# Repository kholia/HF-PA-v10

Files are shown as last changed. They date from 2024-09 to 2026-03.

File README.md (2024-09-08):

Why?

We need a QRP PA which does NOT blow up (unlike those 3xBS170 and 4xBS170
designs). We believe that if the FETs blow up (despite best practices and
intentions but under less-than-ideal external conditions), then the design has
FAILED!

[Inspirational Video Link](https://www.youtube.com/watch?v=4r7wHMg5Yjg)

Update (August-2024): https://github.com/kholia/HF-PA-v10/tree/master/IRFP-Hacks-v5-SMD
(or v4 for THT regulator) and SUPSiC GC2M0280120D is all you need for 30W
All-HF PA for 4 USD. For 30W All-HF PA @ 8.5 USD, my tested MOSFET is CREE
C2M0280120D. Use 7815 regulator for powering the UCC gate driver when using the
`*C2M0280120D` MOSFET. SUPSiC GC3M0280090D works very well too and is our top
choice now (as of September, 2024).

Important update (February-2024): LC match for IRF510 @ 28 MHz. 7 turns FT50-6
and 220pF capacitor. Corrected PAE figure is around 50%. 30v @ drain produces
roughly 10W of clean'ish looking RF output. 24v @ drain produces 6W @ 28 MHz.
17v @ drain produces 3.7W.

March-2024 update: LC match for IRF510 @ 50 MHz. T50-6 4 turns and 180pF
capacitor. 24v @ drain produces clean'ish 28.8 Vpp (~2W). PAE is around 25%.
Such is life...

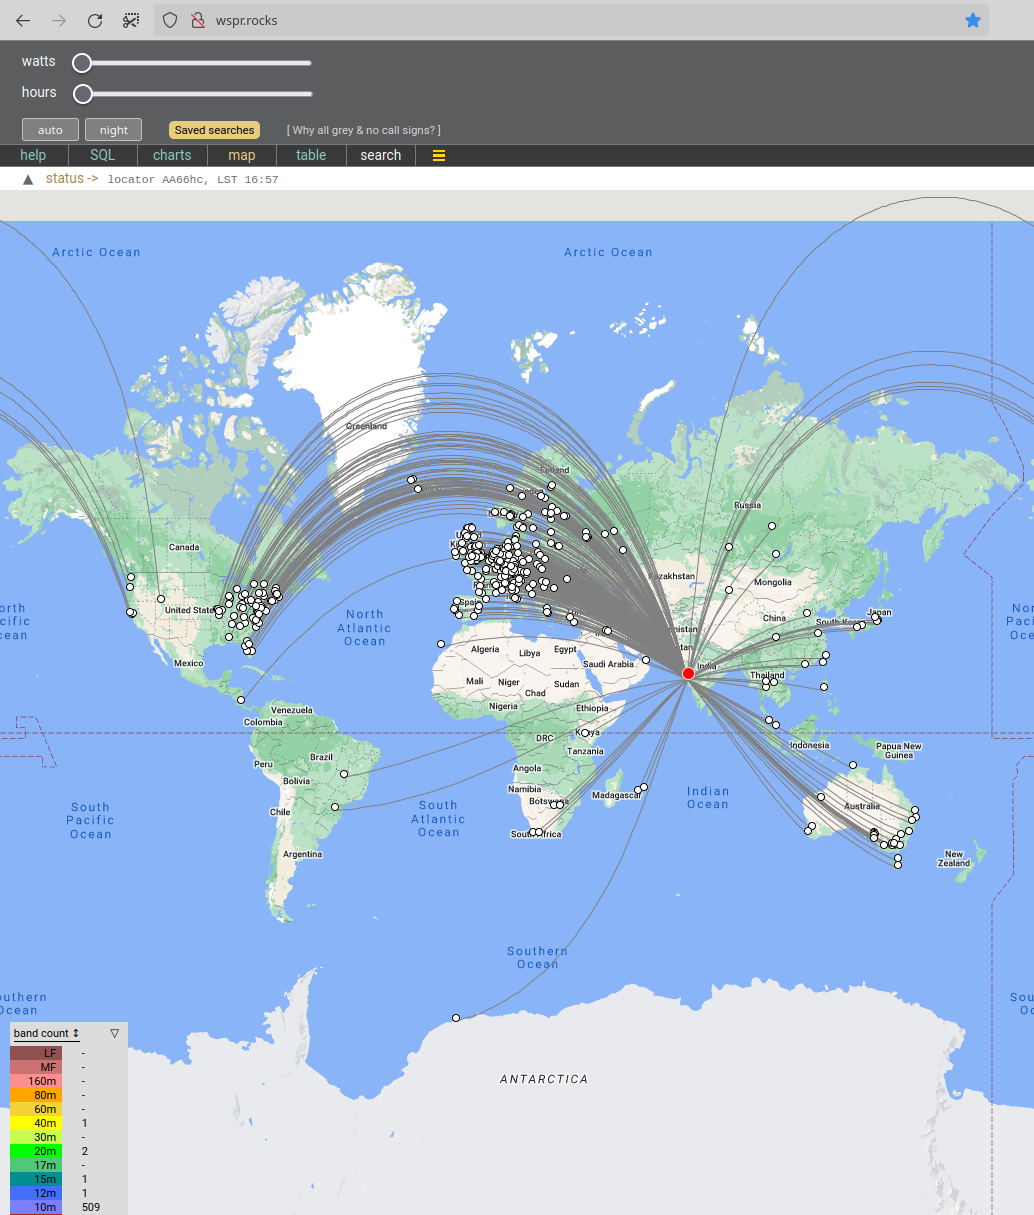
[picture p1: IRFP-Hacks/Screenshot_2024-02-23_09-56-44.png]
WSPR results


Update (29-September-2023): By removing the gate resistor, we firmly push the
amplifier into more Class-D operation. The MOSFET now remains as cool as a
cucumber!

Update (10-September-2023): The PCB was successfully validated!

Output is 7 to 8 W (before LPF) over a range of 160m to 10m as expected, with a
15V SMPS power supply. With a Pro-BPF attached, the power output is ~5W even at
28 MHz with IRF510! It even puts out 2W @ 50 MHz!

Amplifier characterization (@ 30.7 MHz for some reason, before LPF):

7 volts -> 2W

8 volts -> 3W

9 volts -> 3.5W

10 volts -> 4W

11 volts -> 5W

12 volts -> 6W

14 volts -> 8W

Efficiency is in the range of 45 to 50% which isn't bad ;)

Another result: 17 volts. 14 MHz. NKK LPF. 17.3W DC in. 57.6 clean Vpp on
scope. 8.3W clean RF output @ 48% efficiency!

BOM cost (minimal version): < 450 INR only - beat this! ;)

Note: HF-PA-v10 is also known as `CoolAMP (TM)`.

Build Notes:

- Use a 15V / 16v power supply.

- If you want to use a 13.8V power supply, then

  - Do NOT install the 78M12 regulator

  - Bridge the JP2 jumper

- Use adequate heatsinking. I use a 100x100x200 aluminium block with a 12v fan
  for doing WSPR activities. The MOSFET temperature stays under 45 degrees this
  way.

- PTT is active high - 3.3v is enough to trigger PTT.

- To skip the PTT sub-circuit, bridge the AOD407 MOSFET's source to drain.

- This amplifier can be directly driven by Si5351 (use 8mA drive setting)!

- IMPORTANT: For safety and RF output control, use a `10A DC-DC Step-down
  Adjustable Constant Voltage Module` or something similar.

  - https://robu.in/product/10a-dc-dc-step-down-adjustable-constant-voltage-module/

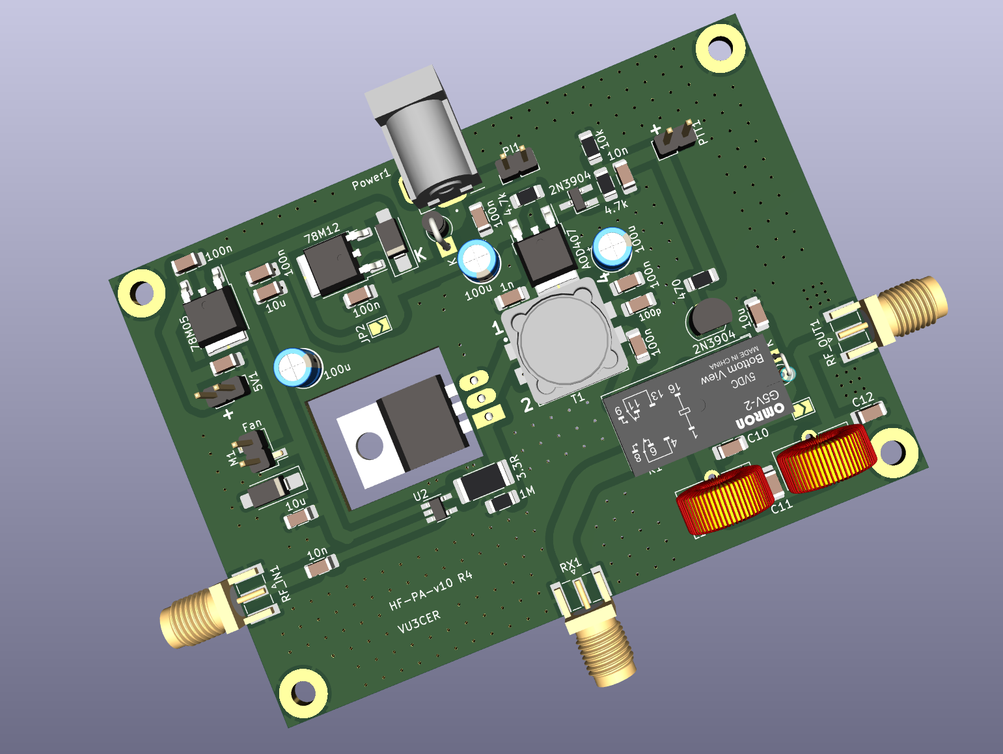
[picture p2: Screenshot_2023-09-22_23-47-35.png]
PA 1


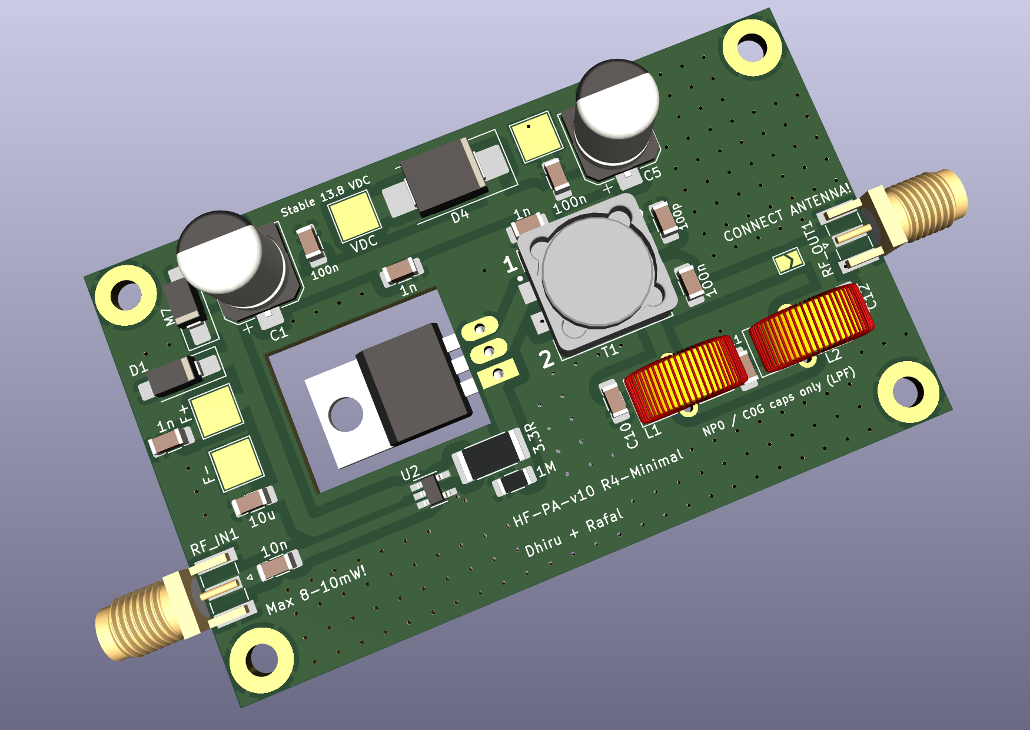
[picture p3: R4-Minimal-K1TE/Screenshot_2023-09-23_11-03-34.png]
PA Minimal


Results:

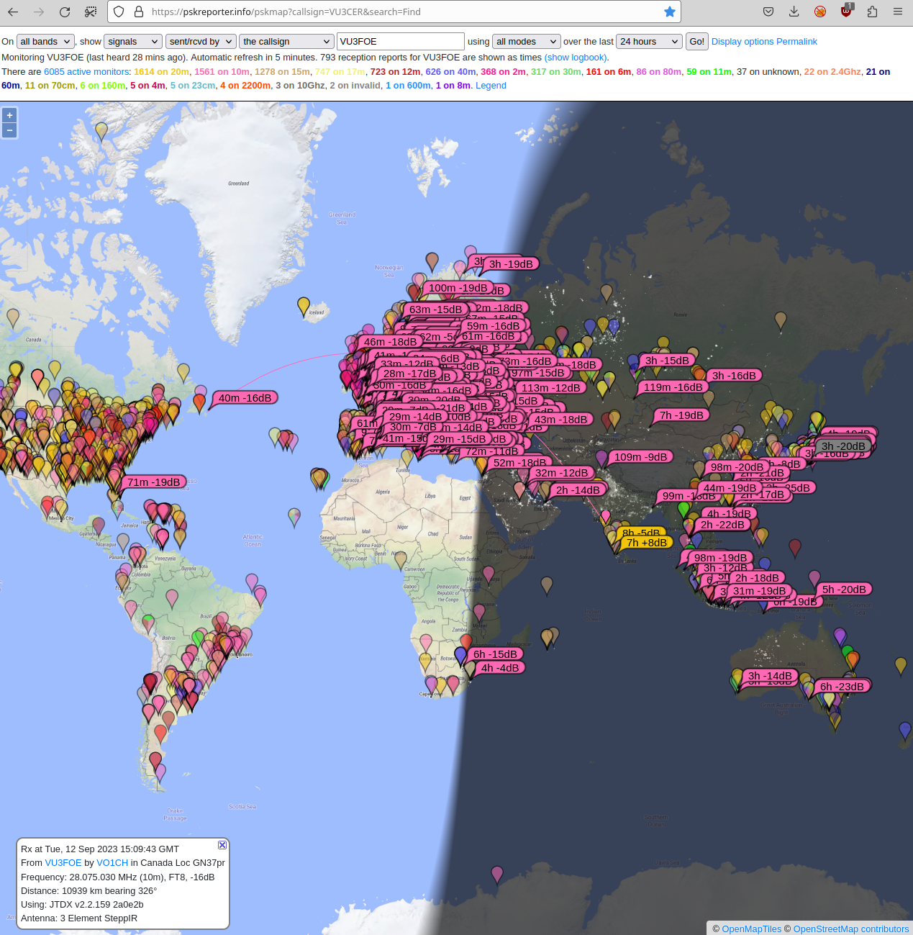
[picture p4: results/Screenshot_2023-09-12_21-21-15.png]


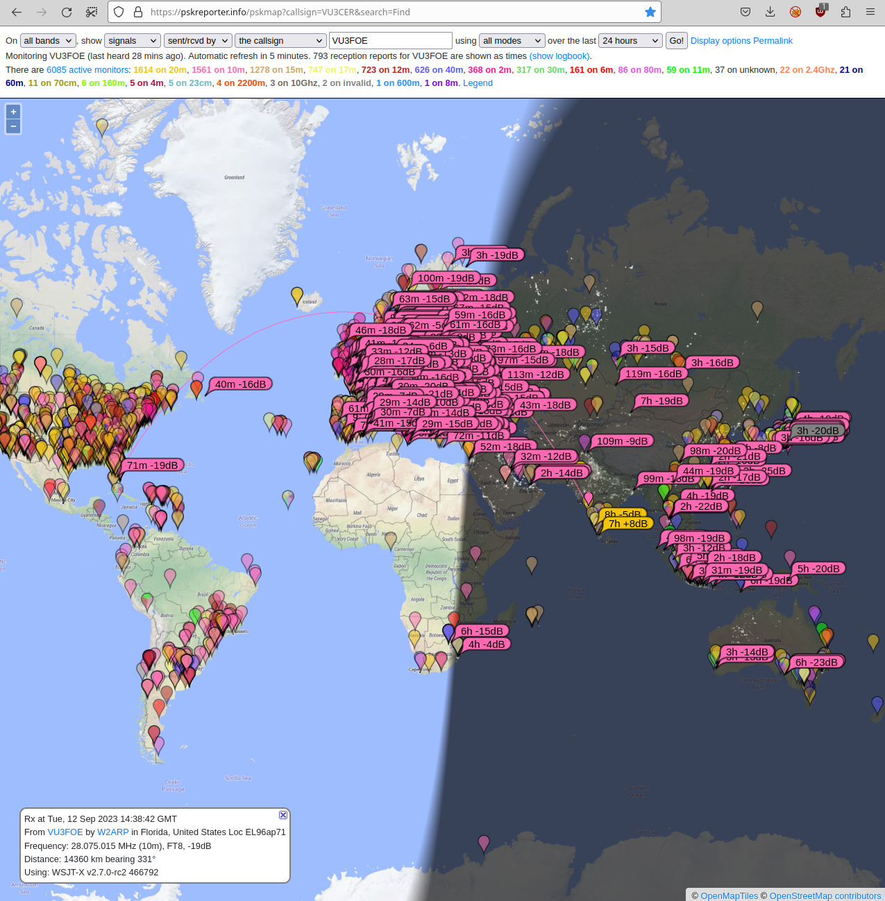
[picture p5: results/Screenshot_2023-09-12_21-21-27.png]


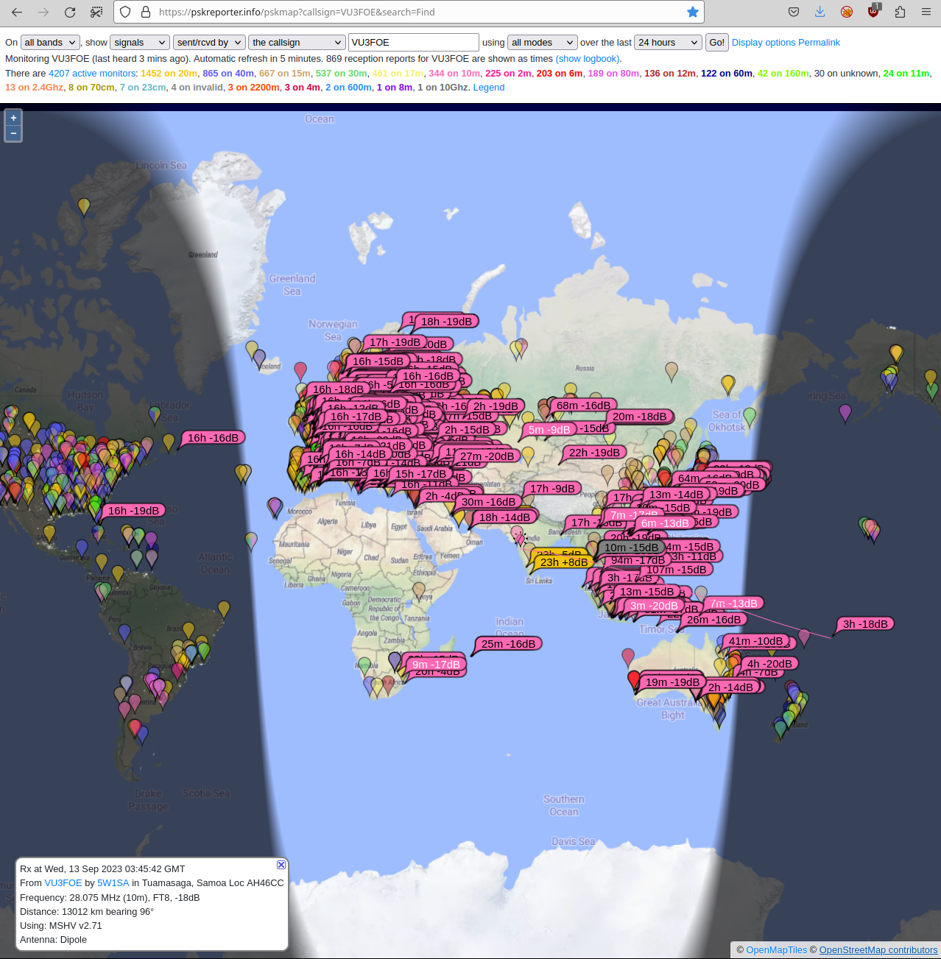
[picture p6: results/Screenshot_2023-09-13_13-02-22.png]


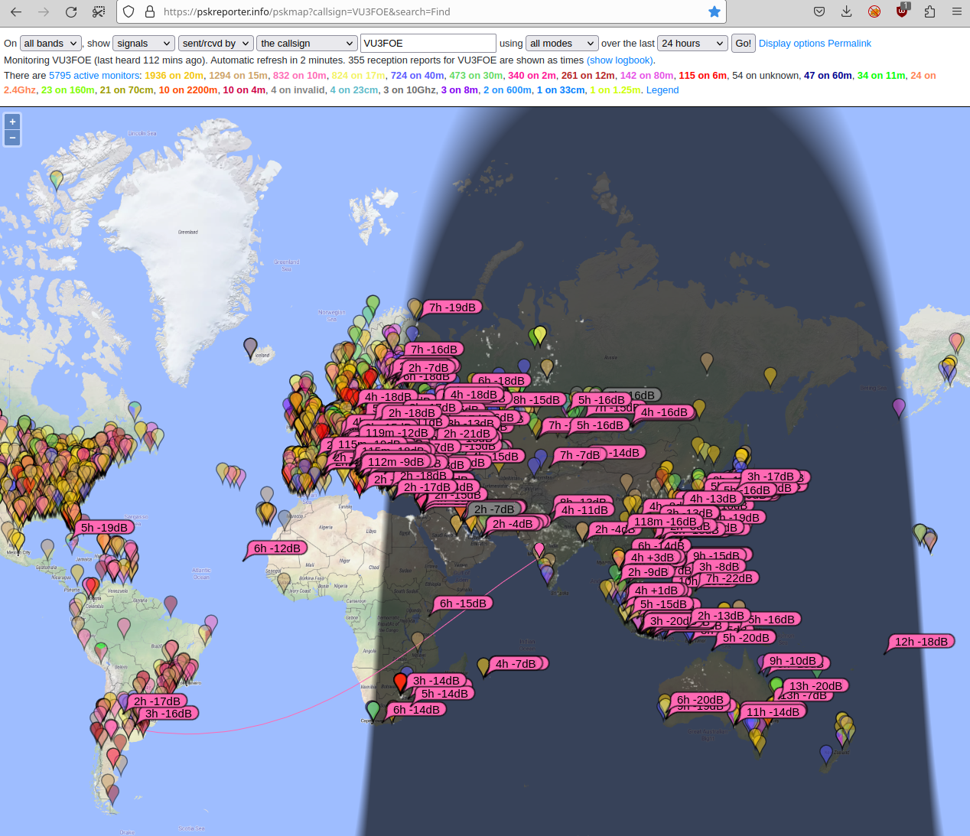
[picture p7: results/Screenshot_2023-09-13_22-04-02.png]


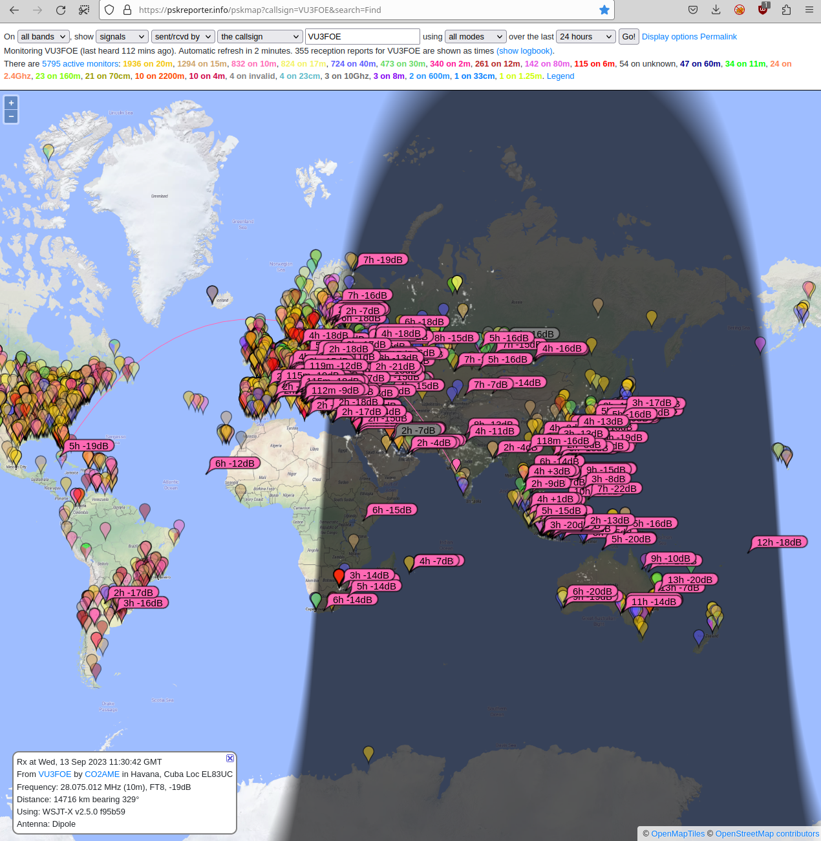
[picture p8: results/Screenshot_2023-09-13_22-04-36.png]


Fun on WSPR:

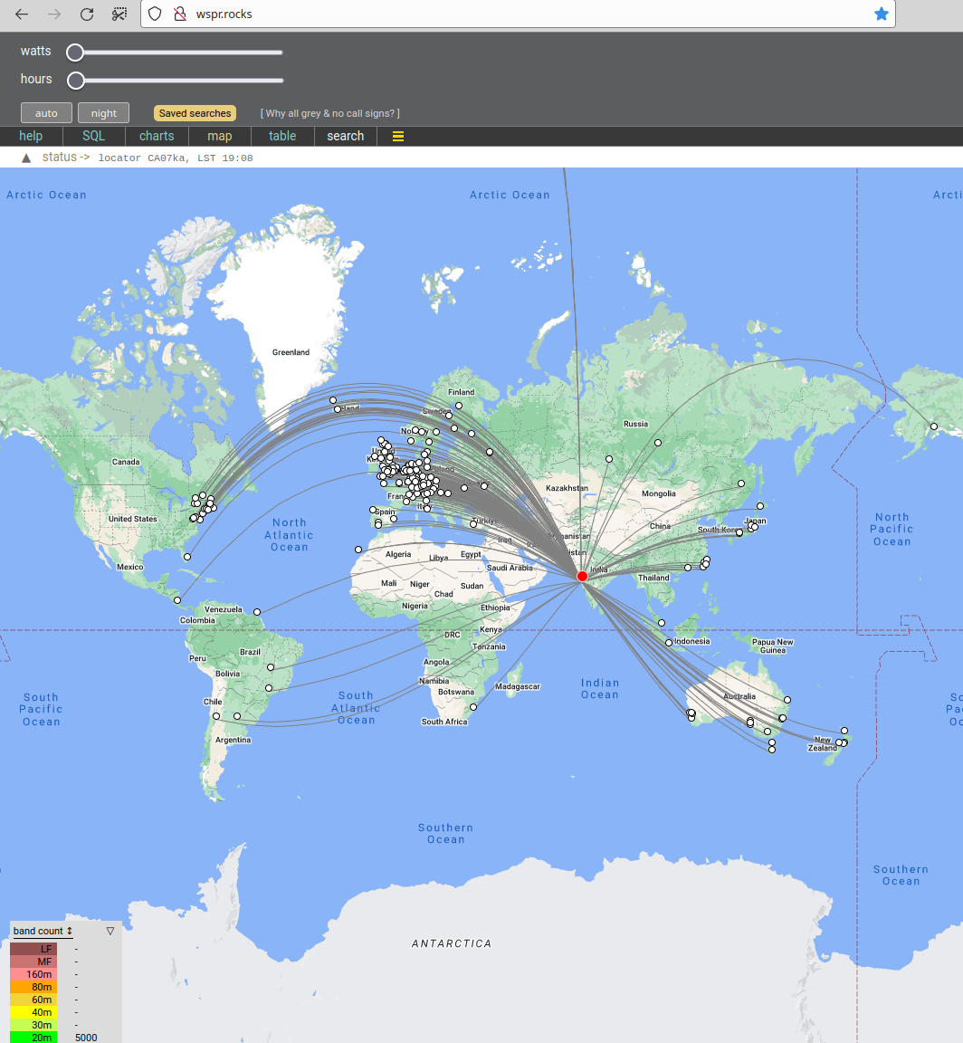
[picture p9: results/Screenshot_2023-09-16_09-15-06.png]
WSPR 1


Note: I am using a 5-meter long EFHW antenna tuned for the 10m band along with
~45 meters of HLF-240 coax. Your results should be better than mine ;)

Quick Hacks:

I am using one v10 board (on low power setting of ~1 to 2W) to drive the second
v10 board.

The second v10 board has IRF530 on it. It uses a simple 3R3 SMD drain choke,
240nH inductor (8 turns on T50-6) + 470 pF LC match for the 20m band at the
output side.

The power output is 20W+ with 30v at the IRF530 drain. While this is fine for
FT8, we decrease the output power to 9 to 12W for WSPR mode (considering
derating, heat dissipation, fear of "flash over")

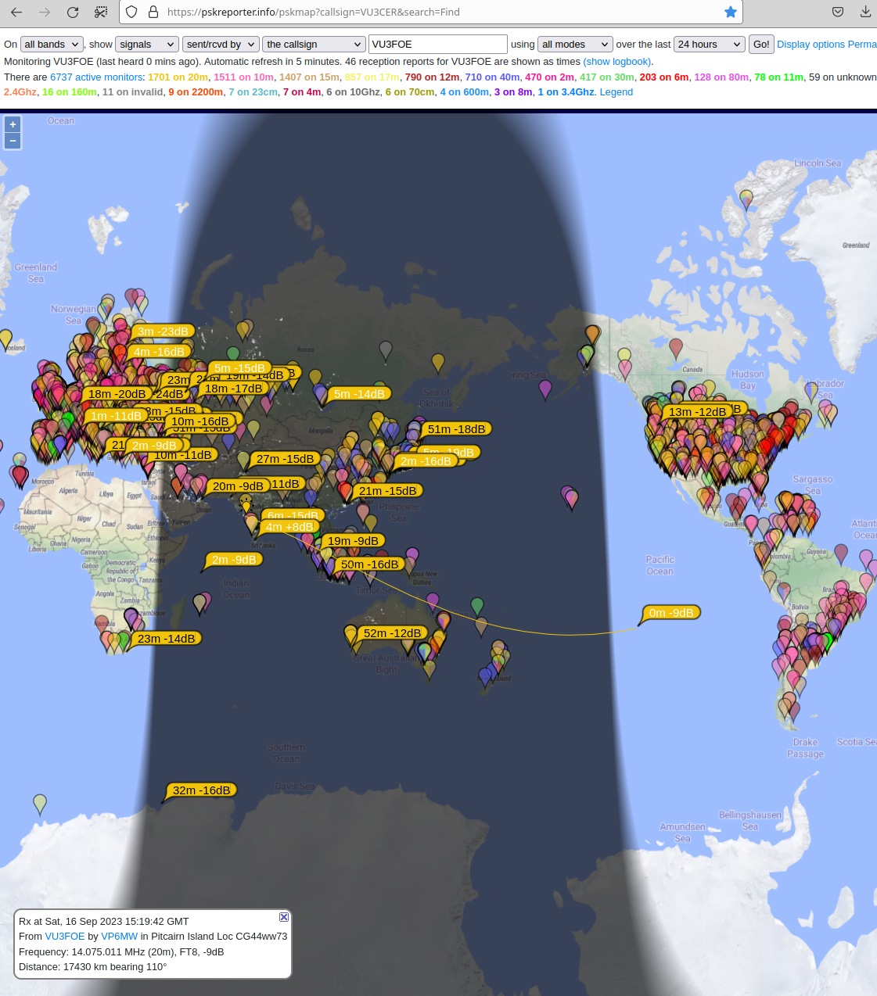
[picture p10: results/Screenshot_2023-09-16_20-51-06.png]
Results for IRF530 hack


December-2023 update: We can now use IRFP140N (with its massive TO-247 package)
to generate around "20W" safely for WSPR. We drive the IRFP140N MOSFET directly
with the UCC driver chip now.

Settings: UCC driver at roughly 12v. With LC match set for 20m band (NB!).

IRFP140N @ 28v drain @ 14 MHz -> 22W

IRFP140N @ 28v drain @ 3.5 MHz -> 20W (for Rafal)

IRFP140N @ 28v drain @ 7 MHz -> 20W

We believe we can push 25W easily by feeding 14v to 15v to the UCC driver chip.

The "final" IRFP140N MOSFET remains as cool as a cucumber, pretty boring -
right? Where have the "exciting" days of the MOSFETs blowing up in your face
gone? Just kidding!

NB: To overcome antenna losses (~2.0 SWR 20m dipole), lossy 50m meters of
HLF-200 coax, we need to generate around 15W+ on the amplifier side.

```
In [1]: 15W * 0.88 (SWR losses) * 0.40 (coax losses)
Out[1]: 5.28
```

PA protection:

- We plan to use INA219 to monitor current consumption, and to terminate TX if
  anomalies are detected.

- Use `thermocouple` attached to the MOSFET's body using thermoglue to monitor
  the temperature, and to terminate TX if anomalies are detected.

New discoveries (via https://github.com/rafal-rozestwinski):

- Power output is 1 to 1.5W on 50 MHz.

- The PA survives open and short conditions but protections are recommended in
  any case.

  - INA219 based current monitoring

  - Thermocouple based temperature monitoring

- We do NOT recommend the old-skool SWR monitoring approach due to its
  complexity (for end-users).

Learnings:

- Keep the IRF510's gate voltage <=9 volts.

  If the IRF510's gate voltage is too high (i.e. when IRF510 is over-driven),
  it results in super wide-band distorted noisy signal on the output - you
  don't want that ;)

  If you want to feed high voltages to IRF's drain, then use a regulator (9v)
  for powering the UCC driver chip.

Joining In:

Are you interested in such projects, and spam-free technical discussions?

If yes, you might be interested in joining [the 'HAMBREWERS' Telegram group](https://t.me/+TwzGyKGe8_QI_B3y).

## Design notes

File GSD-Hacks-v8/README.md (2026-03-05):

This version uses a GaN gate driver (MX1025D) and GSD pinout TO-252 package GaN FET. It also uses a cost-effective Chinese `coupled inductor`.

Works without extra cooling at 12V to 15V drain. 20V drain needs extra cooling for heavy duty cycles. 

For WSPR, I recommend running at 7.5V drain with ~1W output.

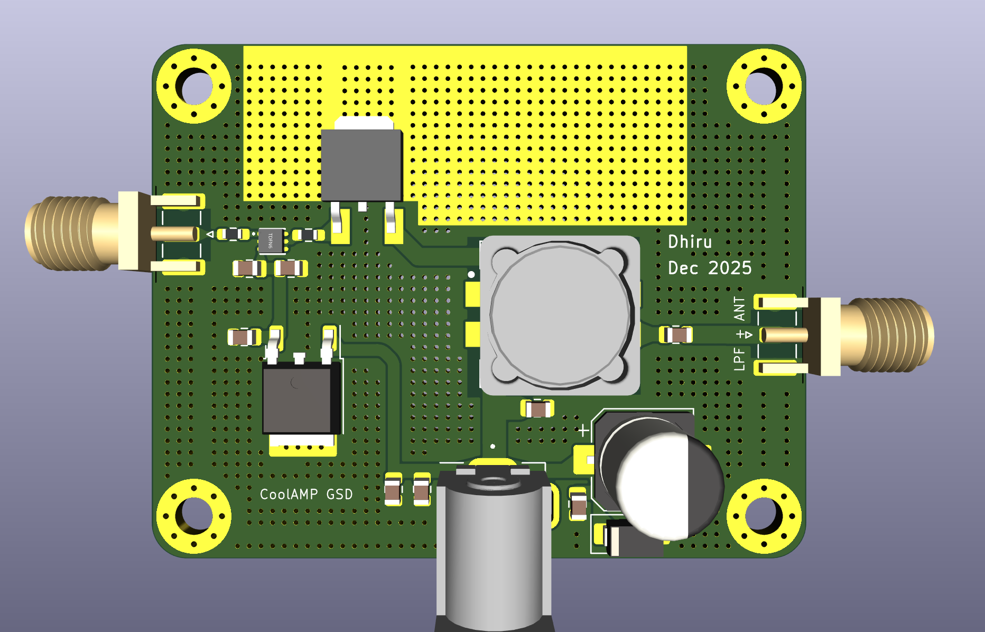
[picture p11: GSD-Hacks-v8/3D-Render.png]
3D PCB Render


This is the same as `GSD-Hacks-v7` but with an 10 ohms series resistor added to the TTL input port.

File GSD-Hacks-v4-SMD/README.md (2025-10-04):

This version uses SOIC-8 gate driver (NCP81074ADR2G) and GSD pinout TO-252 package FET.

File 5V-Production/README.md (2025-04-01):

This version was created to allow easier experimentation with `VCC = 5v`.

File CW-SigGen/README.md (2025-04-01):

Many RF MOSFETs specify a CW input signal in their datasheets.

This `CW-SigGen` software produces a suitable CW input signal for testing power
amplifier circuits.

This was tested on a WeMos D1 Mini board connected to a Si5351 module.

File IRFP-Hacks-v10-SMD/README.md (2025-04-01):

This version was created to allow easier experimentation with `VCC = 5v`.

This version also uses SOP-8 gate driver(s).

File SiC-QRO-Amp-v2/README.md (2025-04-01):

NB: This design is inspired by the wonderful `Single NXP MRF-101 Eval Board`
project by Jim Veatch.

This project is similar to `SiC-QRO-Amp` one.

Changes:

- Use a SOIC-8 MOSFET driver instead of our usual SOT23-5 one

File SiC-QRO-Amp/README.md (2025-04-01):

NB: This design is inspired by the wonderful `Single NXP MRF-101 Eval Board`
project by Jim Veatch.

https://sites.google.com/site/rfpowertools/rf-power-tools

Backstory: Sometimes we all need a bit of "QRO" in life...

So we give you the `Baby QRO` switching amplifier!

MRF101 is too "precious" for WSPR usage, especially with its self-limiting
TO-220 package.

This PCB was tested in late January-2025 and it works great. Produces 100W+ at
50V drain on 7 MHz. The gain drops with increasing frequency but not too badly!

Results:

[Conservative] 9V driver, 43V drain -> ~70W @ 7 MHz, 60W @ 14 MHz, 30W @ 28 MHz

12V driver, 43V drain -> 50W @ 28 MHz, ~70W @ 7 MHz. Efficiency is close to 50
percent on 28 MHz it seems. 55% efficiency at 7 MHz.

[TOP] 12V driver, 48V drain -> 60W @ 28 MHz, 100W @ 7 MHz.

Cost for 100W: Around 15 dollars (for all including PCB and BOM components)

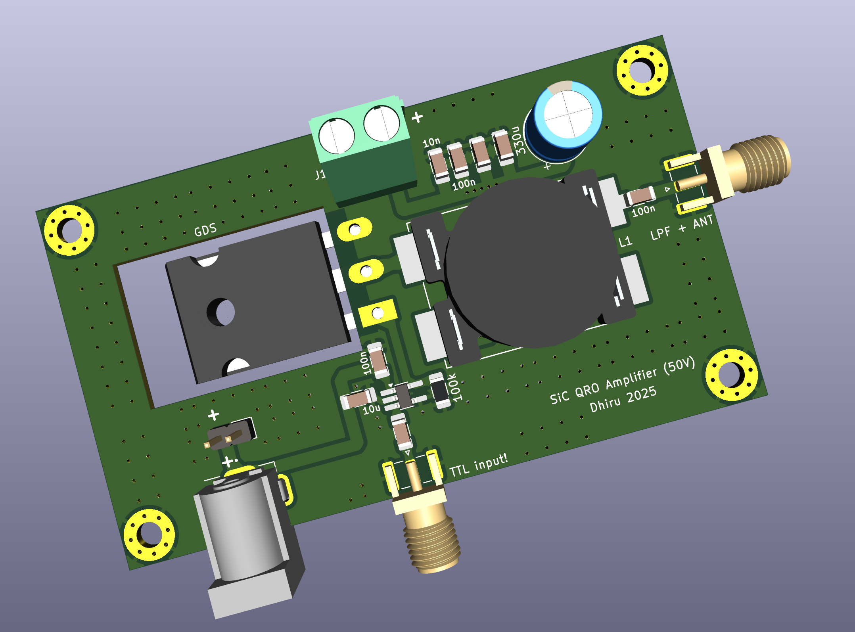
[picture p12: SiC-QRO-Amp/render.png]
Render


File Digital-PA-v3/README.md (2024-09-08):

# Digital-PA
A digital mode power amplifier for 160-10m.
Created using Kicad 7.0.6.

Licensed under Attribution-NonCommercial 4.0 (CC BY-NC 4.0).

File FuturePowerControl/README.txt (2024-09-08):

https://electronics.stackexchange.com/questions/630076/buck-converter-adjustable-output-voltage-using-digital-potentiometer

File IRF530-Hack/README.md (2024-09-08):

IRF530 hack. ~1.5W in, 20W+ out on 20m @ 25v to 30v drain.

ATTENTION: Use a fast fan when doing digital modes using this PA.

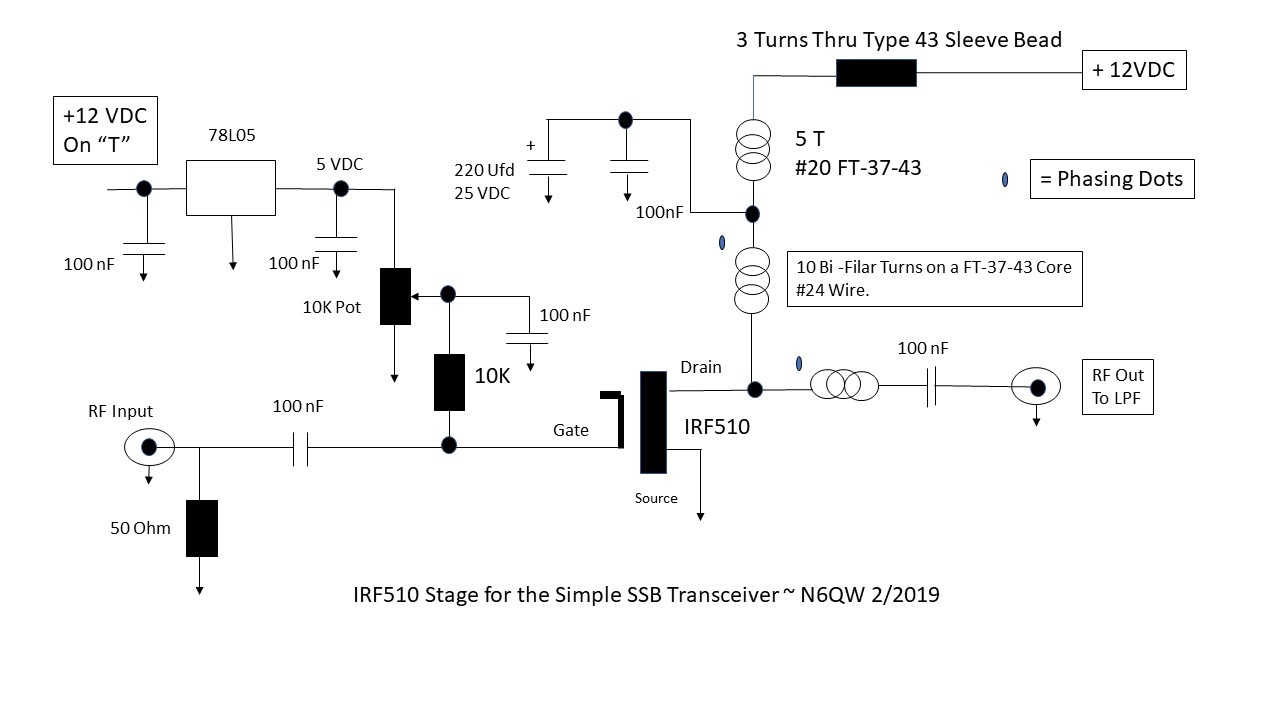
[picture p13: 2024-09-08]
Linear-Amp-SSB-v1/IRF510 Schematic.jpg

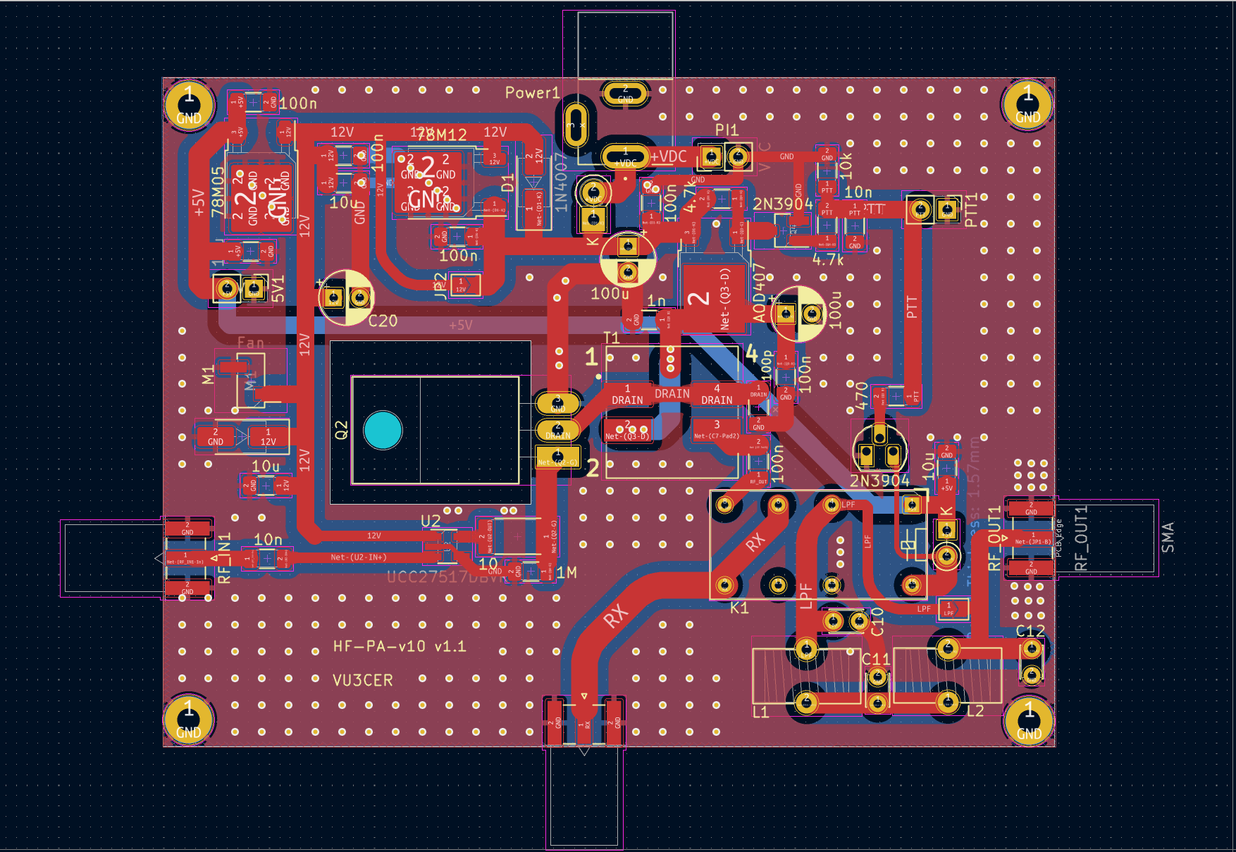
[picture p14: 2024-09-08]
Screenshot_2023-08-26_22-36-42.png

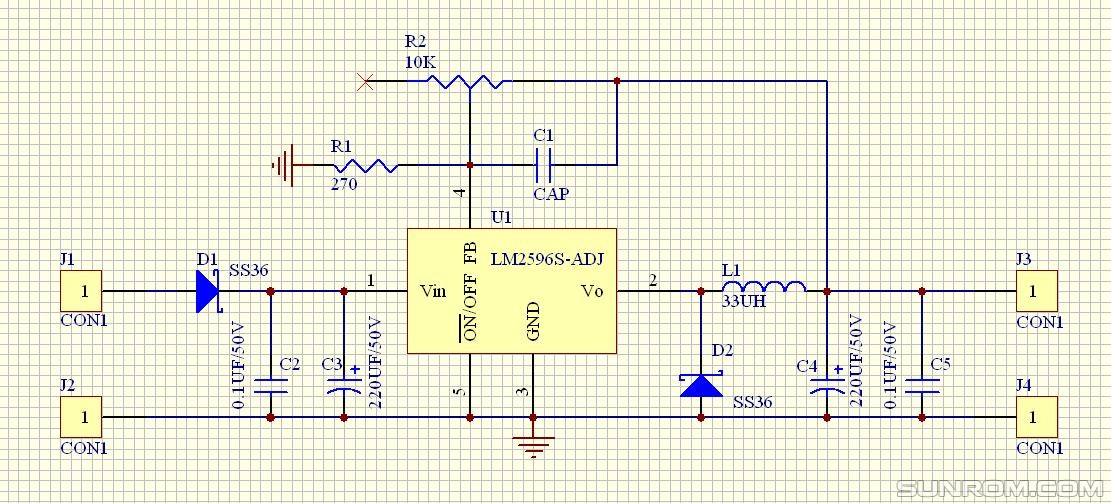
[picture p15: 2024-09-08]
FuturePowerControl/sch.jpg

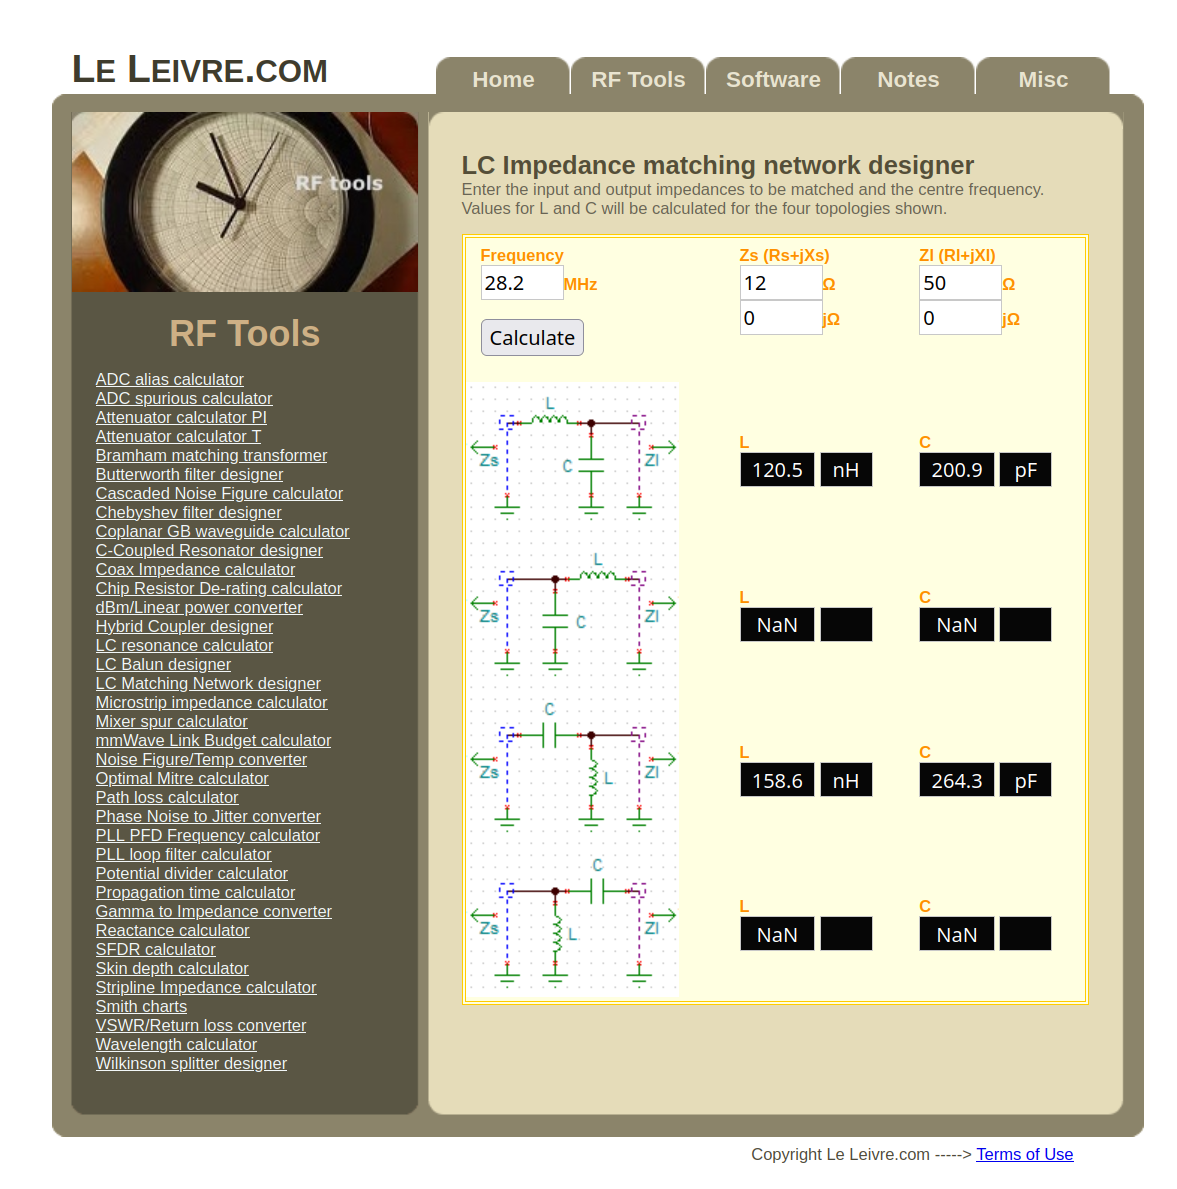
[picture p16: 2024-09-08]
IRFP-Hacks-v7-SMD-With-SSB/info/Screenshot_2024-04-25_09-21-08.png

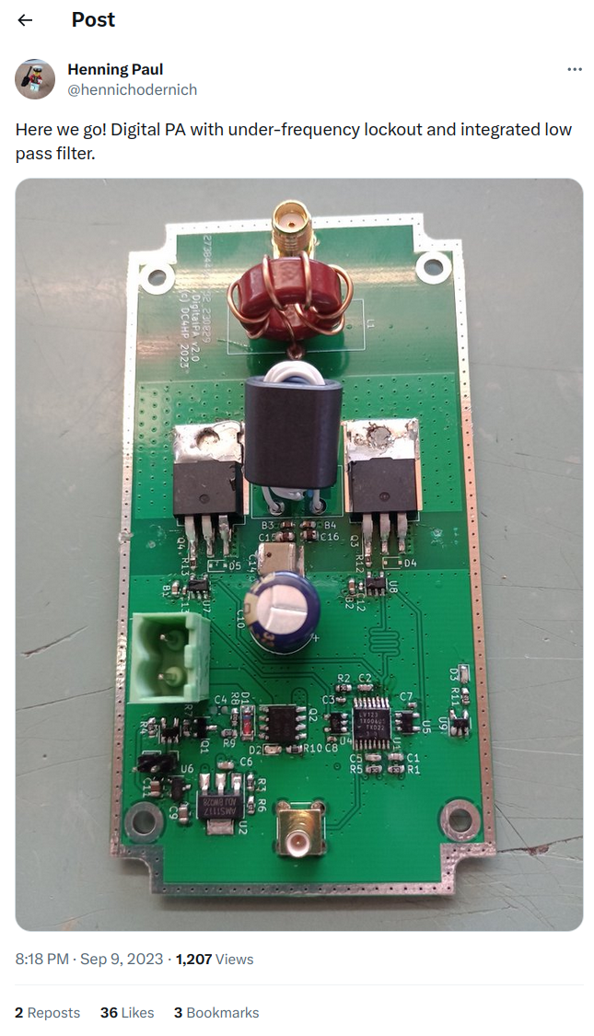
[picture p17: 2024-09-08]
info/Screenshot_2023-09-10_00-21-56.png

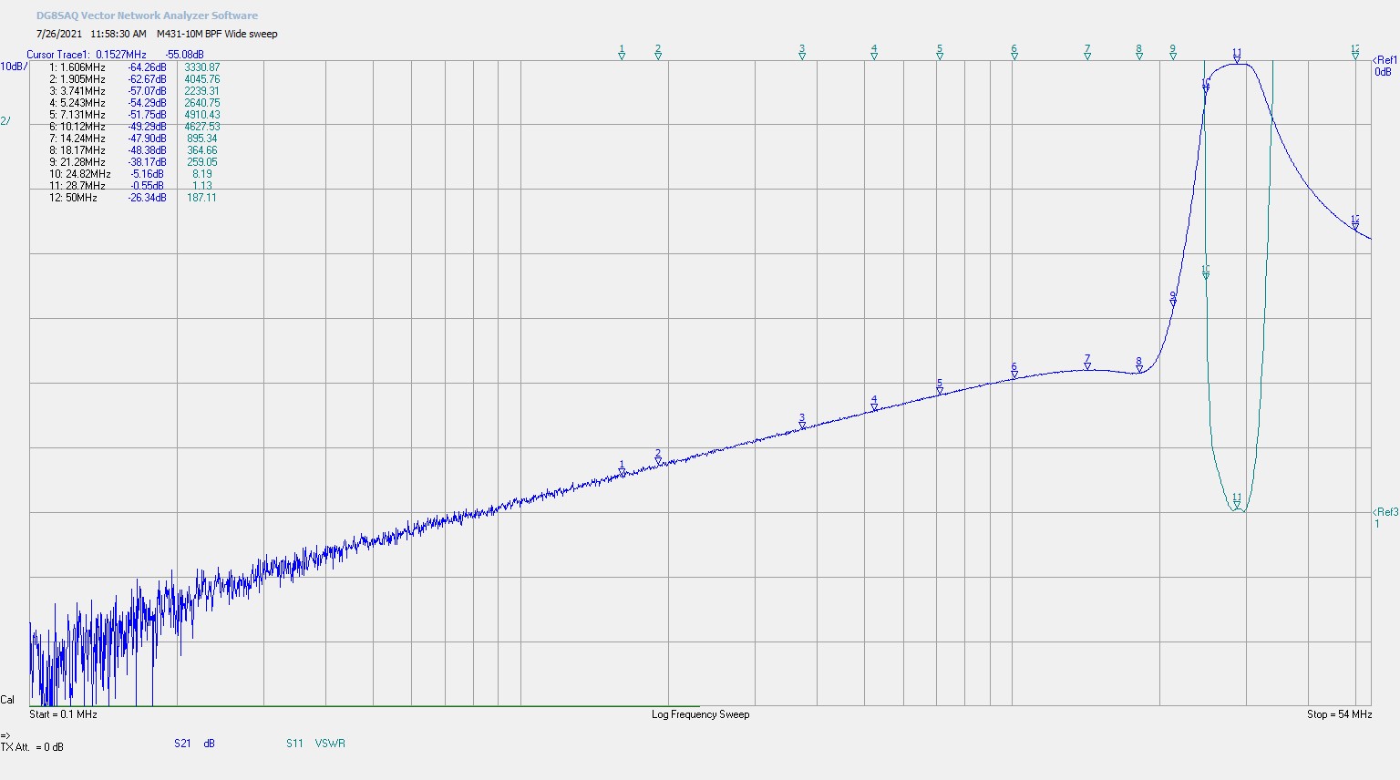
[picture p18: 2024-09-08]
info/M431_10M_Wide.jpg

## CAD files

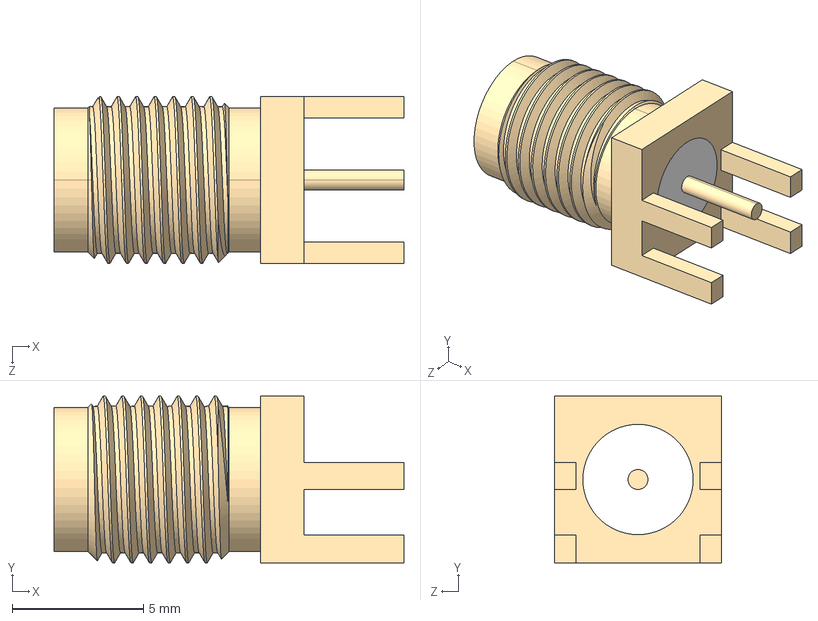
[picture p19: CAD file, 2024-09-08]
3-Pole-LPF/models/CON-SMA-EDGE-S--3DModel-STEP-56544.STEP
13.3 x 6.35 x 6.35 mm

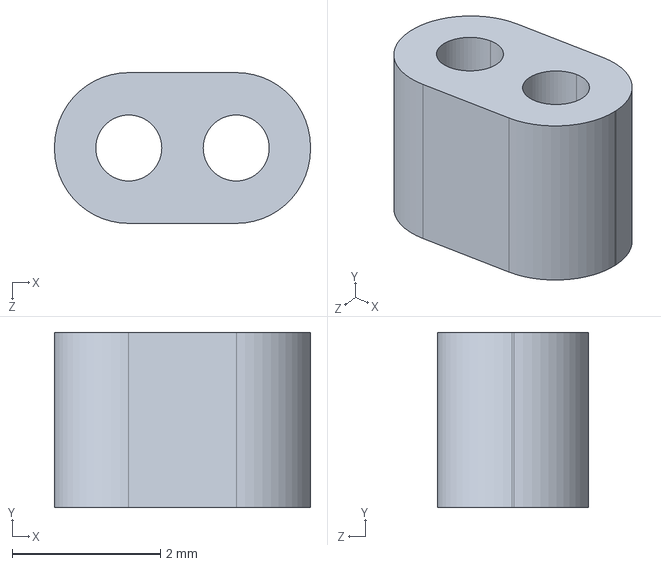
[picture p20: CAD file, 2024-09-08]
Digital-PA-v5-Prod/models/User Library-BN43-2302.STEP
3.45 x 2.36 x 2.03 mm

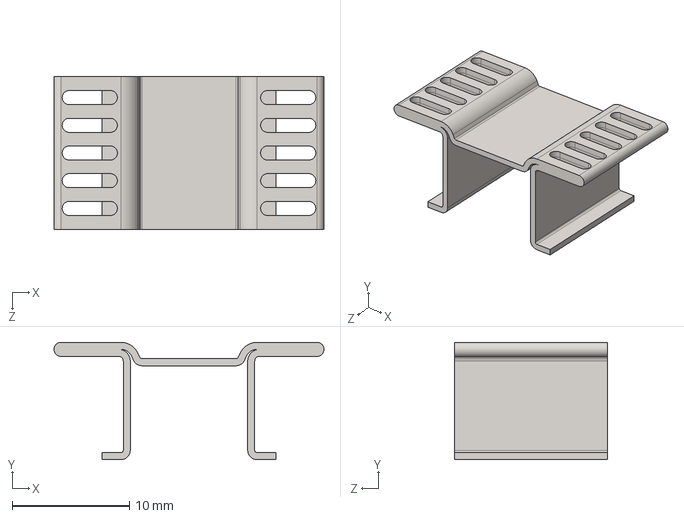
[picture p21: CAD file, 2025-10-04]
GSD-Hacks-v8/models/FK_244_13_D_PAK_TR.stp
23.0 x 10.0 x 13.0 mm

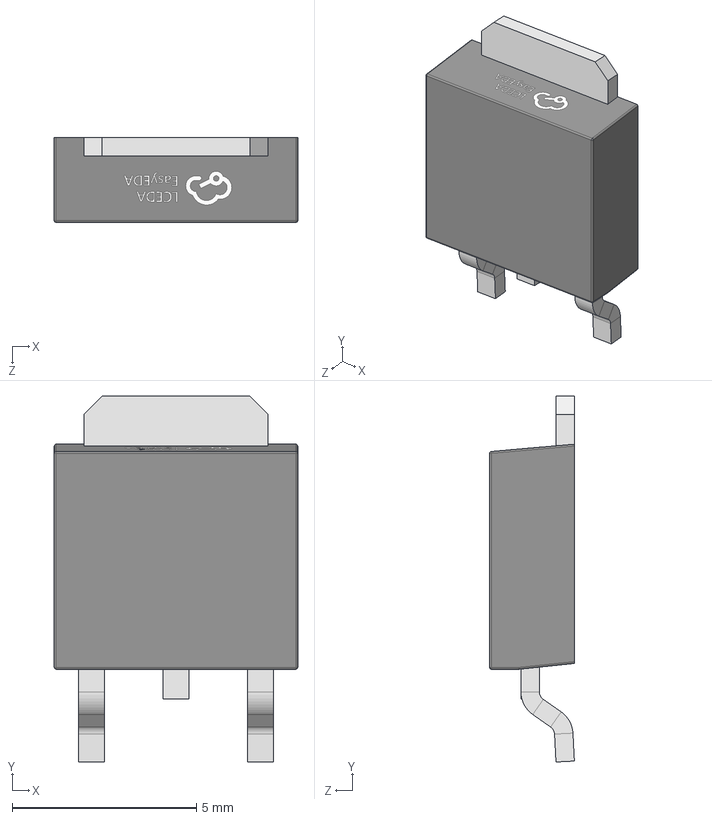
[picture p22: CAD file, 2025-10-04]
GSD-Hacks-v8/models/TO-252-2L-3P_L6.6-W6.1-H2.3-LS10.1-P4.6.step
6.60 x 9.92 x 2.30 mm

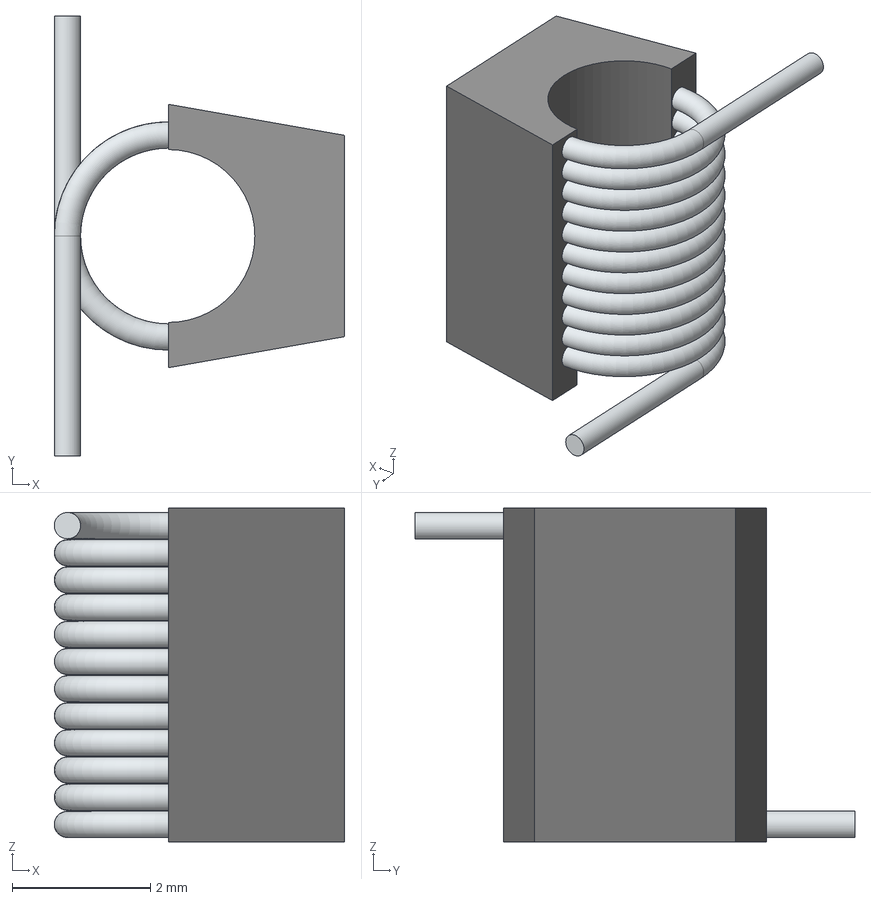
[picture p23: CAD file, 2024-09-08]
MRF101-Hack/models/WE-CAIR_4248 (rev1).stp
4.20 x 6.36 x 4.83 mm

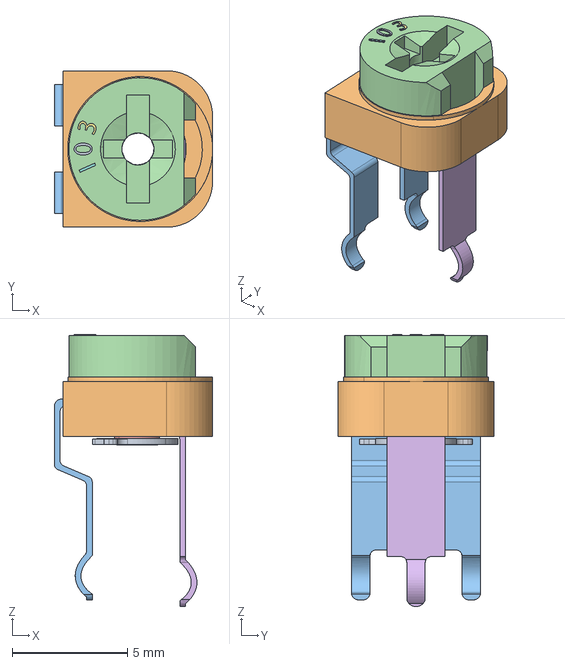
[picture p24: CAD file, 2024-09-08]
UCC-Driver-Board/models/Poti_10kohm.stp
6.88 x 6.80 x 11.8 mm

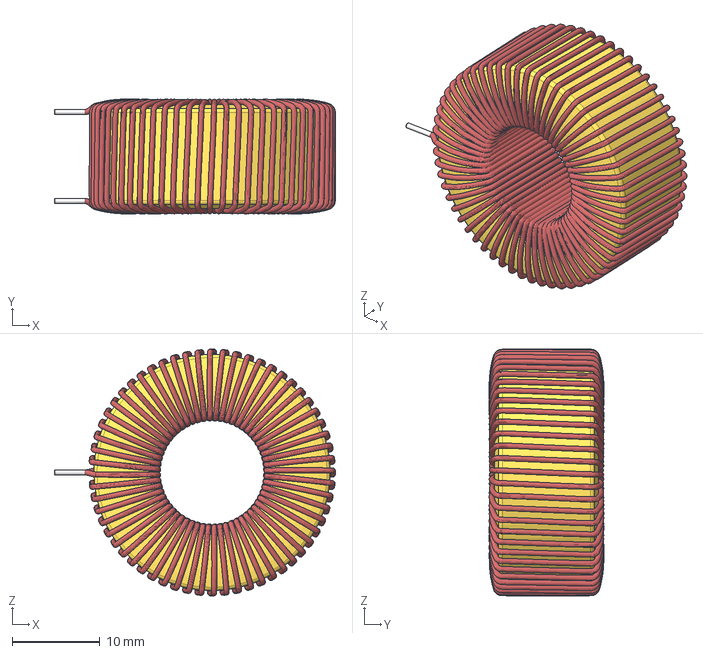
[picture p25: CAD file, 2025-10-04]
GSD-Hacks-v8/models/Toroidal_Inductor_330uH_3A.stp
32.1 x 13.1 x 28.2 mm

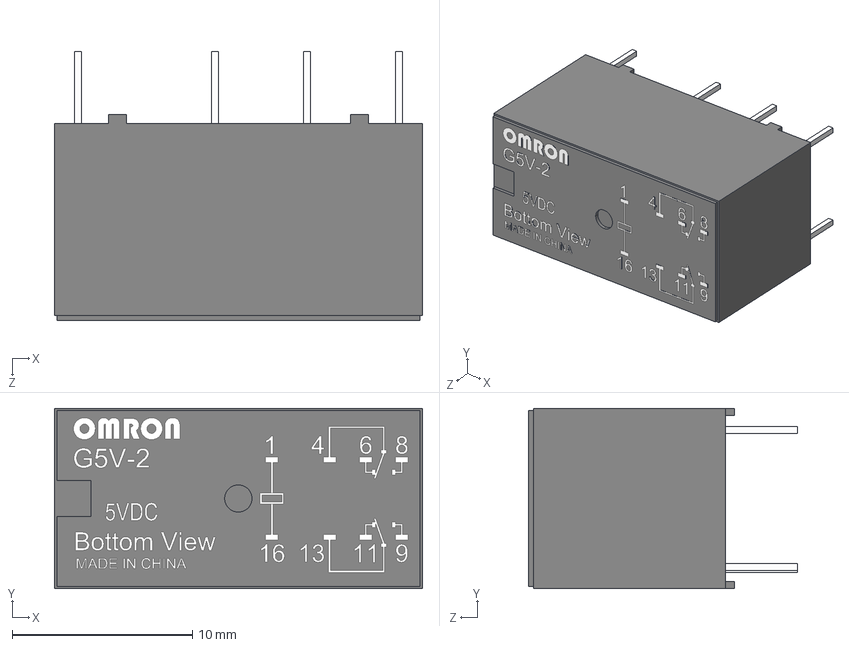
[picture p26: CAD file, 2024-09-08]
MRF101-Hack/models/User Library-OMRON G5V-2.STEP
20.4 x 10.0 x 14.9 mm

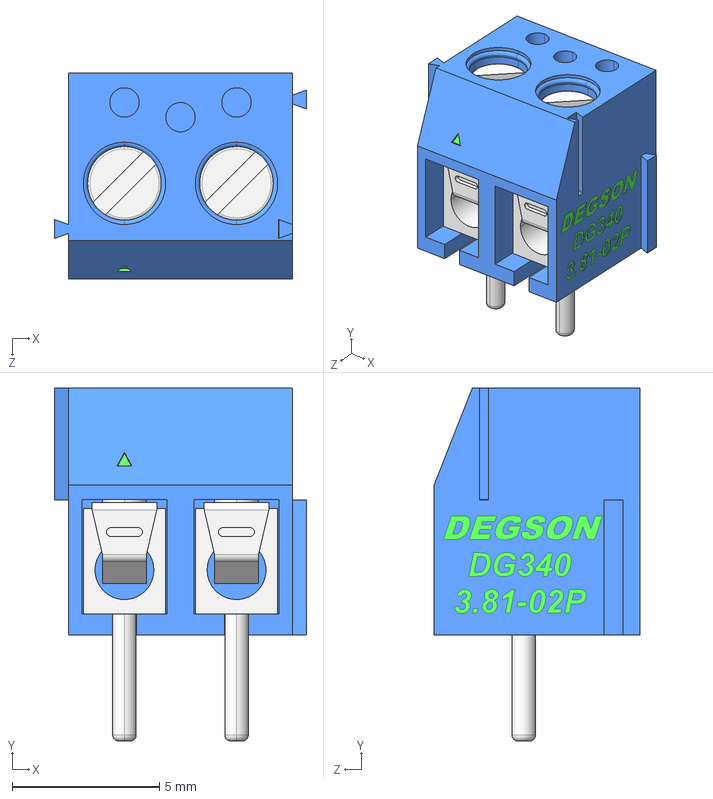
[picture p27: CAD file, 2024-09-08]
MRF101-Hack/models/DG340-3.81-02P-12-00AH.STEP
8.58 x 12.0 x 7.00 mm

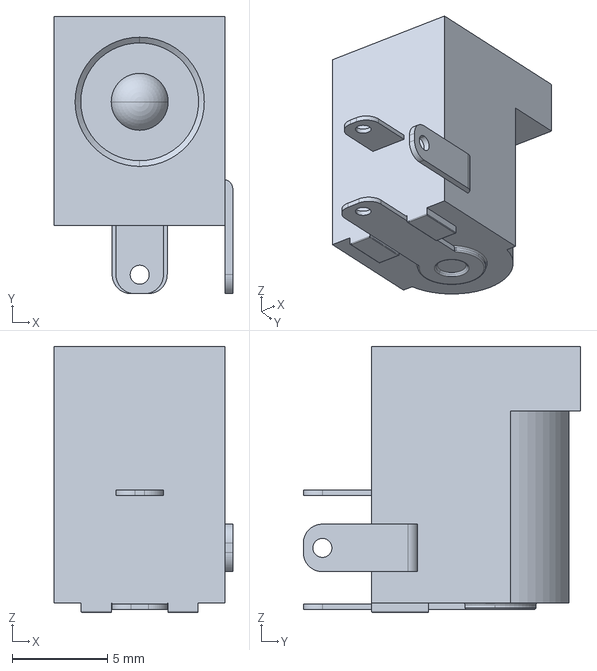
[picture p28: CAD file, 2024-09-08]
GSD-Hacks-v8/models/DC-005-5A-2.0.step
9.40 x 14.6 x 14.0 mm

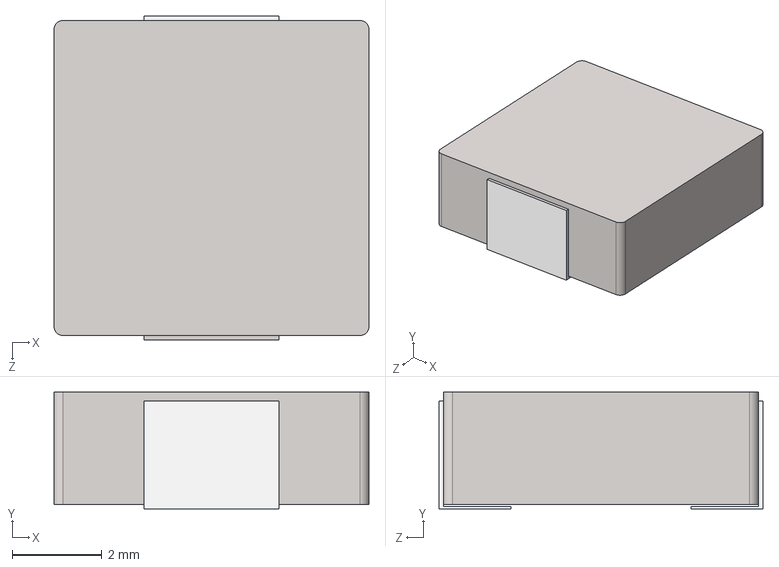
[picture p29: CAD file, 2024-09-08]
MRF101-Hack/models/Inductor_7x7x2.5.STEP
7.00 x 2.60 x 7.20 mm

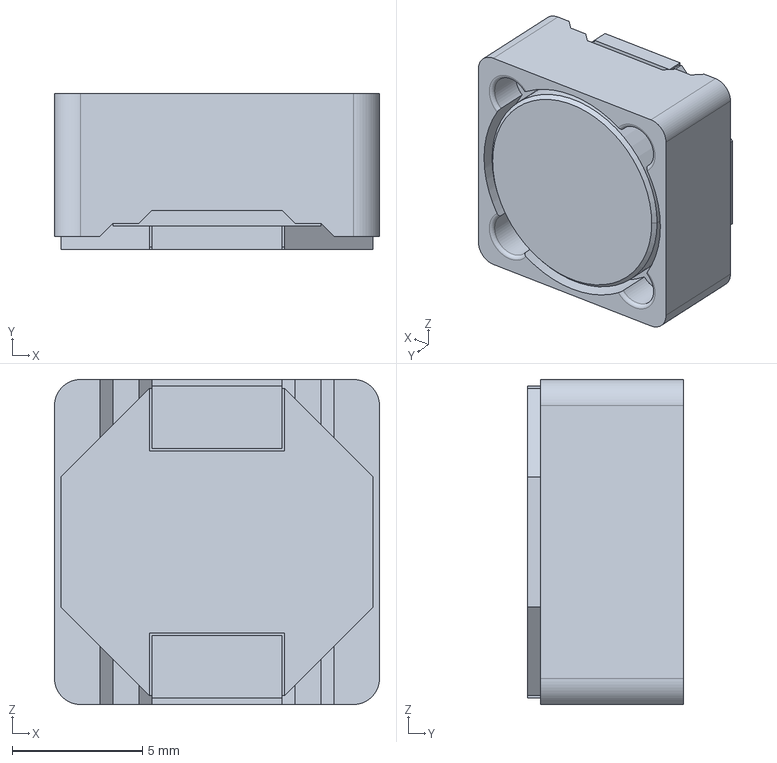
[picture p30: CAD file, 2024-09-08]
MRF101-Hack/models/SRR1260-4R7Y.stp
12.5 x 6.00 x 12.5 mm

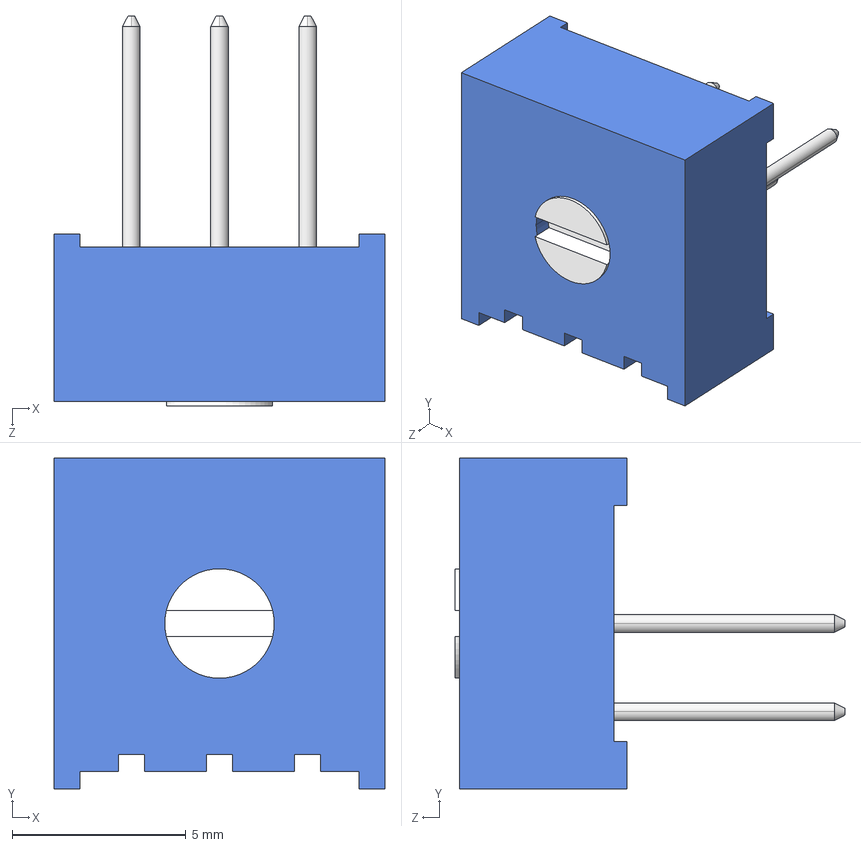
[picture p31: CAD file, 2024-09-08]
MRF101-Hack/models/User Library-3386P.STEP
9.53 x 9.53 x 11.2 mm

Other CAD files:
5V-Production/models/UCC27517DBVR.step
Digital-PA-v3/models/144743.stp
Digital-PA-v3/models/UCC27517DBVR.step
Digital-PA-v5-Prod/models/144743.stp
Digital-PA-v5-Prod/models/UCC27517DBVR.step
FuturePowerControl/models/UCC27517DBVR.step
GSD-Hacks-v1-SMD/models/UCC27517DBVR.step
GSD-Hacks-v2-SMD/models/UCC27517DBVR.step
GSD-Hacks-v3-SMD/models/UCC27517DBVR.step
GSD-Hacks-v4-SMD/models/UCC27517DBVR.step
GSD-Hacks-v5/models/UCC27517DBVR.step
GSD-Hacks-v7/models/UCC27517DBVR.step
GSD-Hacks-v8/models/TO-220-3 Bend Mirror.stp
GSD-Hacks-v8/models/UCC27517DBVR.step
IRF530-Hack/models/UCC27517DBVR.step
IRFP-Hacks-v10-SMD/models/UCC27517DBVR.step
IRFP-Hacks-v2/models/UCC27517DBVR.step
IRFP-Hacks-v3/models/UCC27517DBVR.step
IRFP-Hacks-v4/models/UCC27517DBVR.step
IRFP-Hacks-v5-SMD/models/UCC27517DBVR.step
IRFP-Hacks-v7-SMD-With-SSB/models/UCC27517DBVR.step
IRFP-Hacks-v8-SMD/models/UCC27517DBVR.step
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

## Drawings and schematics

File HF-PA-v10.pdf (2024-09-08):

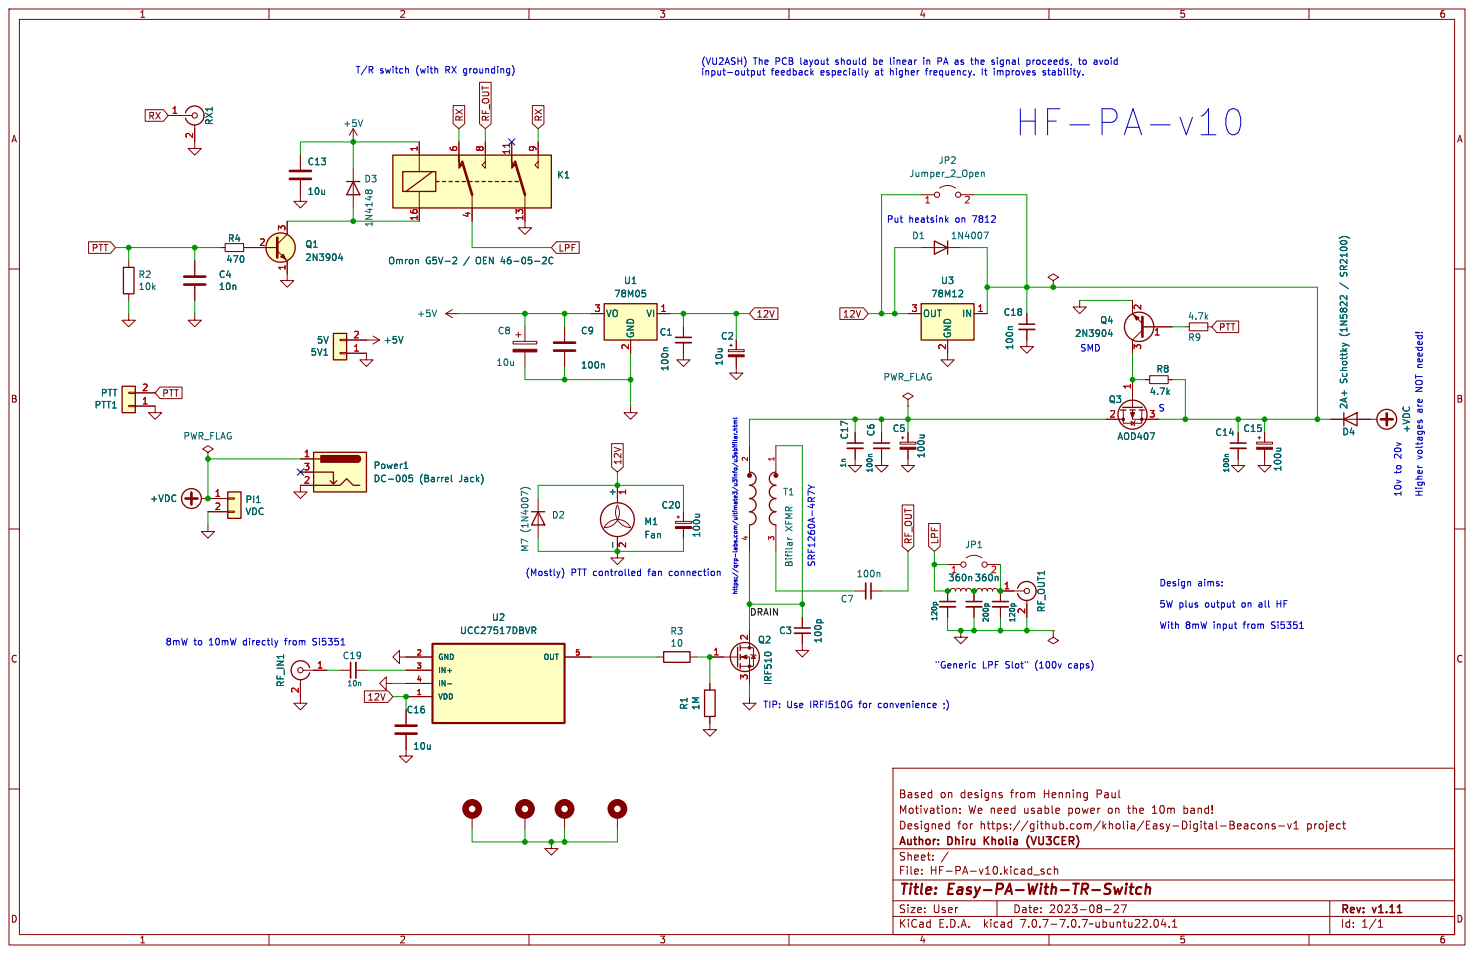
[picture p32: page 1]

"Generic LPF Slot" (100v caps)

Id: 1/1 Title: Easy-PA-With-TR-Switch

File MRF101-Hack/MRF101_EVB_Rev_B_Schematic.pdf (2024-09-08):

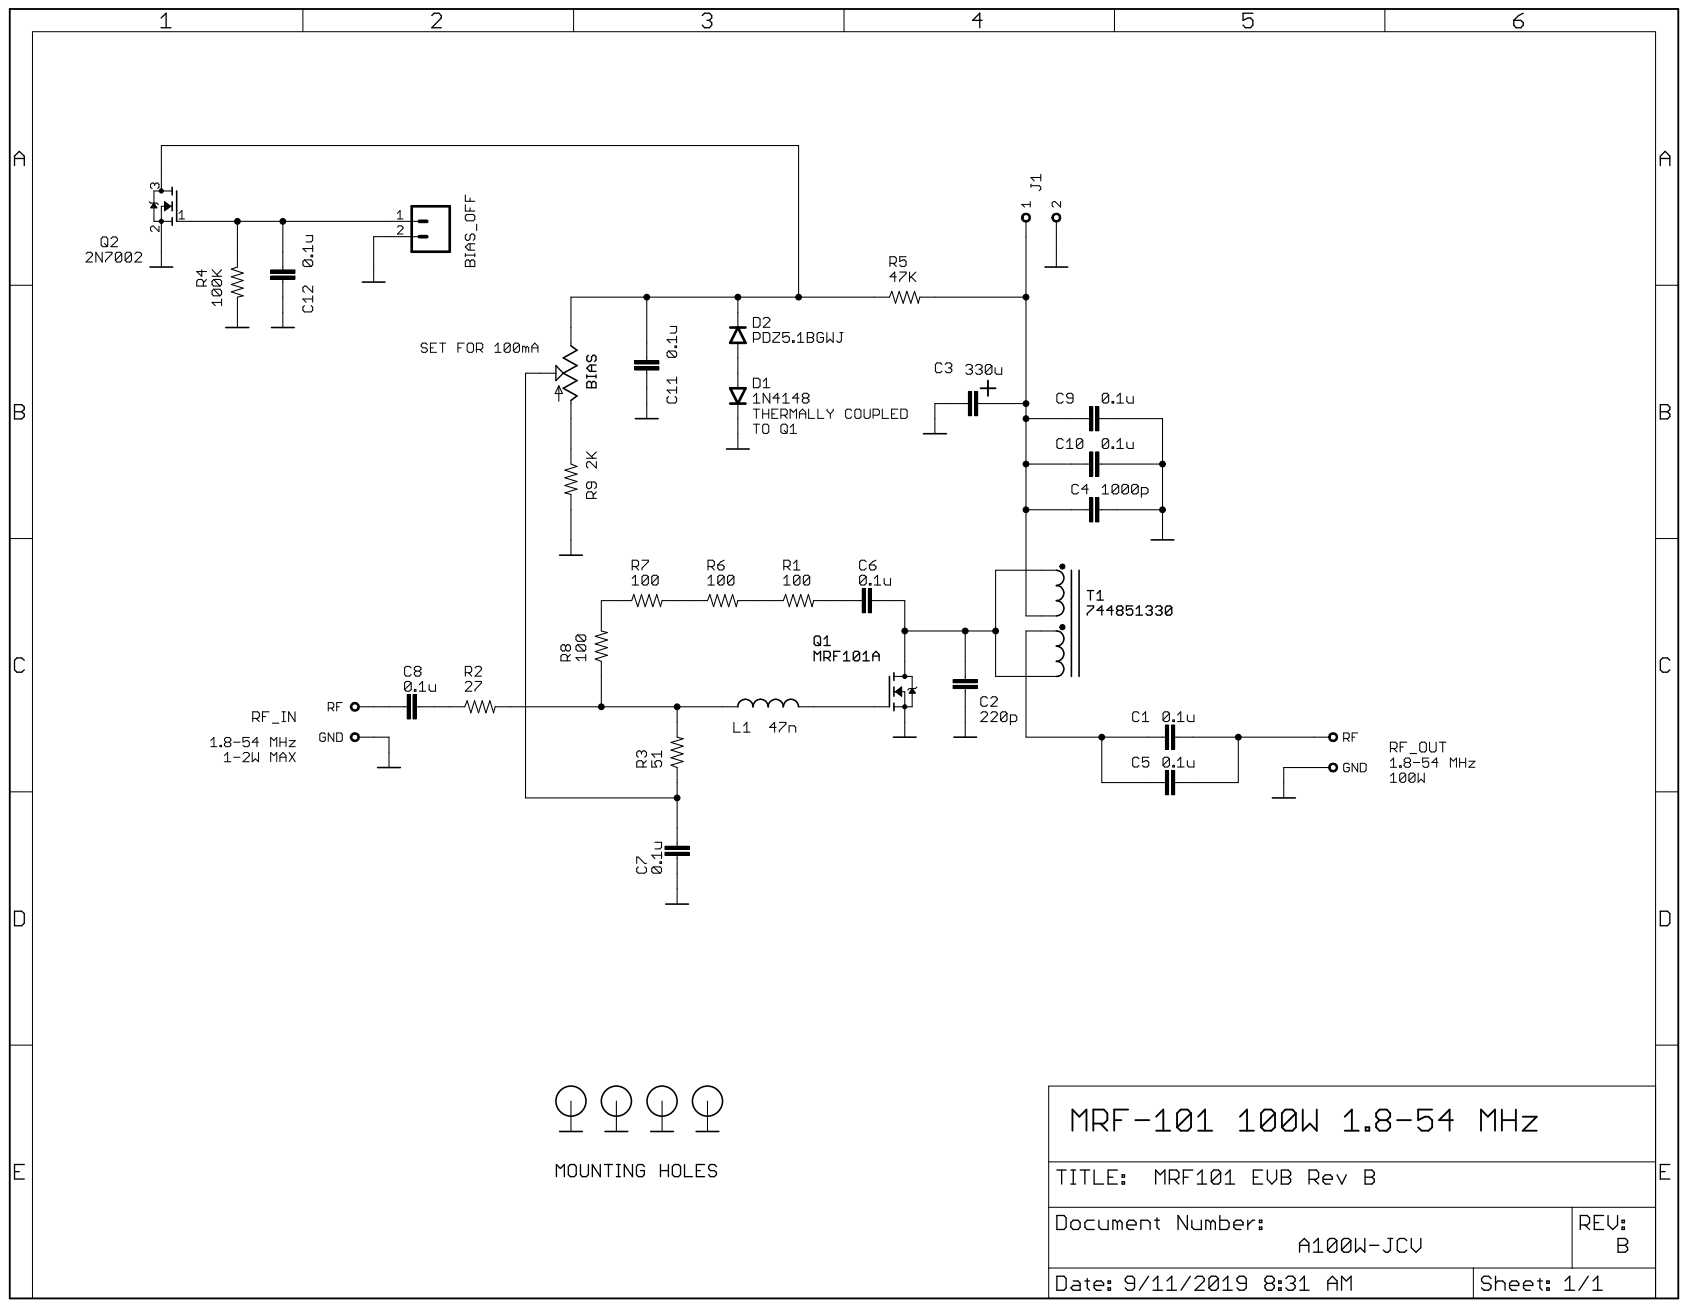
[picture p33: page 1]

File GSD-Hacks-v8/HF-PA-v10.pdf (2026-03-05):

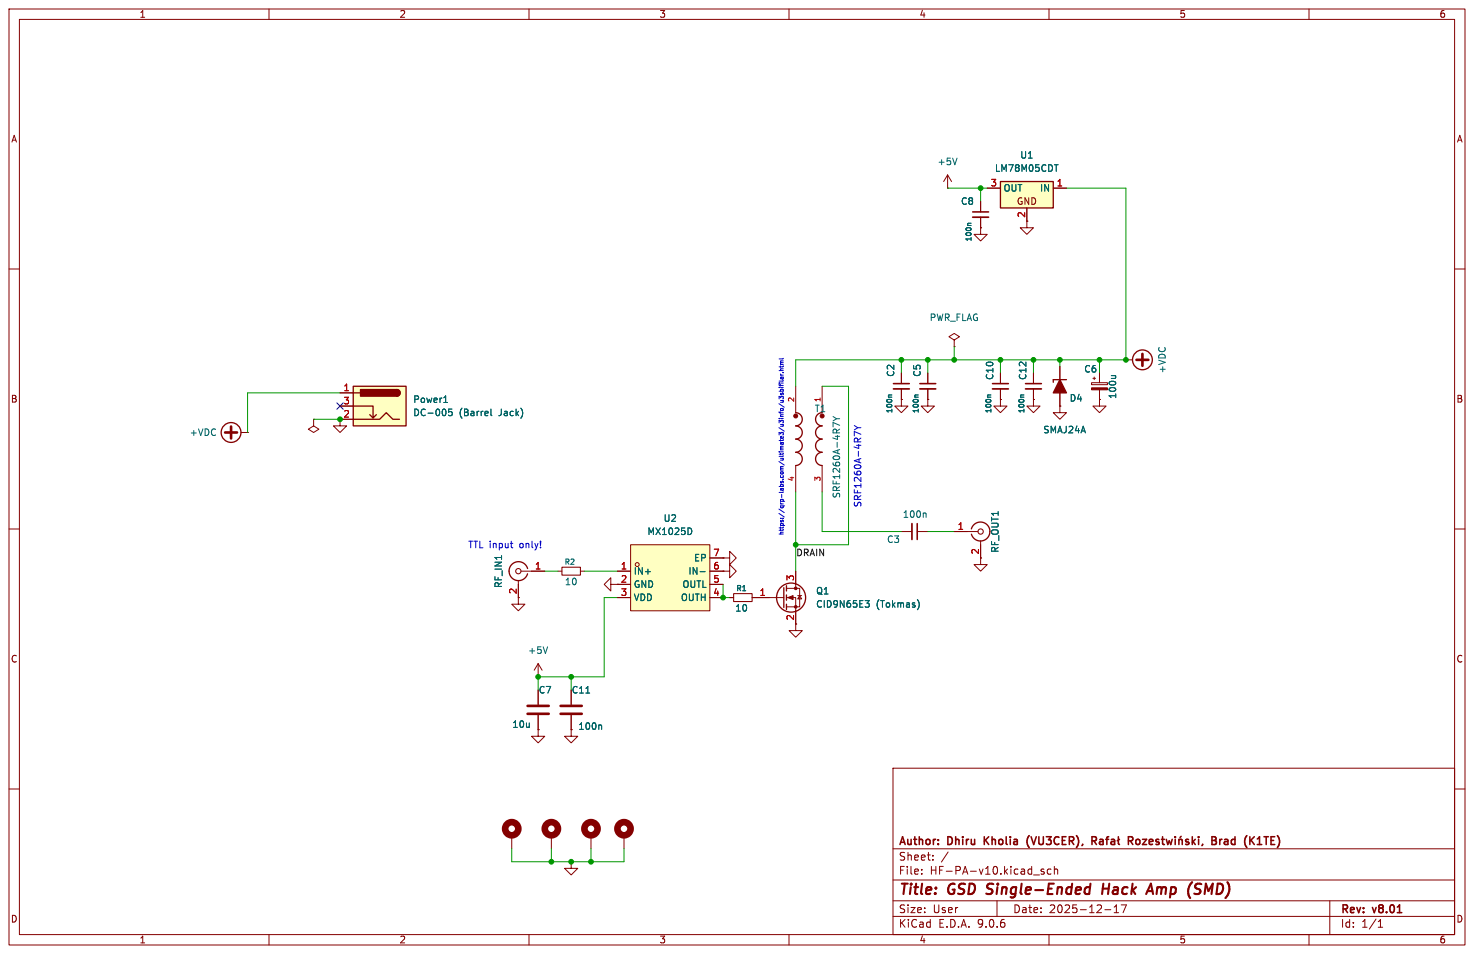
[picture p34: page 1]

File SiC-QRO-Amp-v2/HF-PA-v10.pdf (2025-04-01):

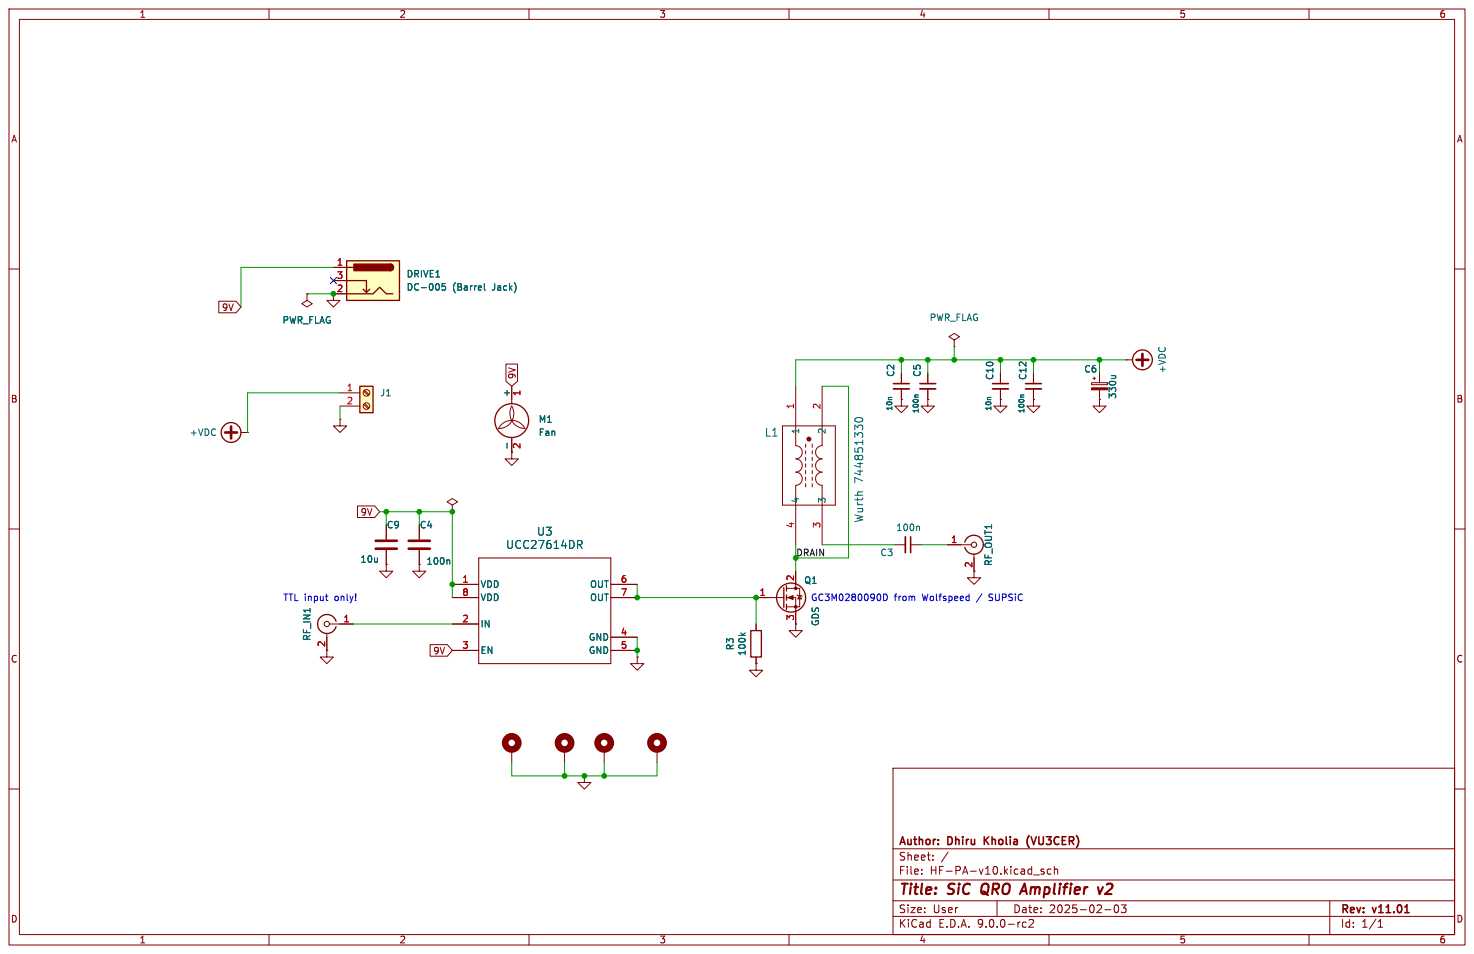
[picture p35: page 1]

Id: 1/1 Title: SiC QRO Amplifier v2

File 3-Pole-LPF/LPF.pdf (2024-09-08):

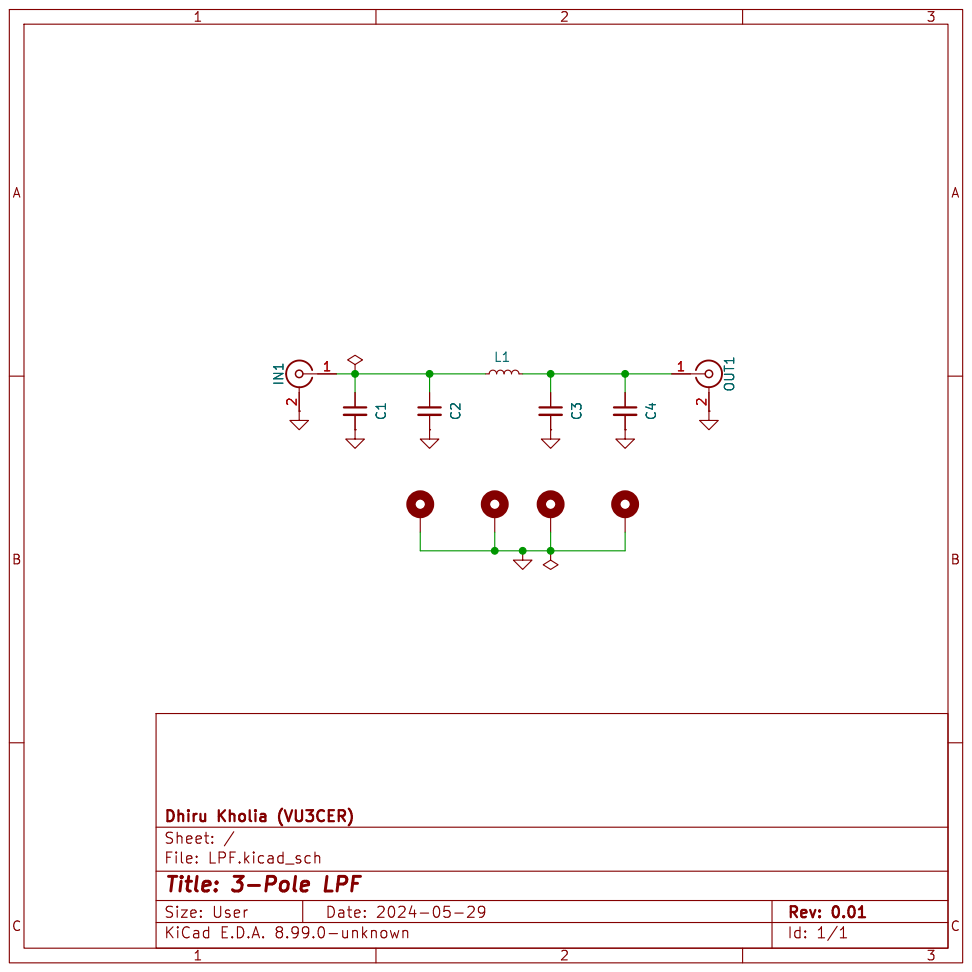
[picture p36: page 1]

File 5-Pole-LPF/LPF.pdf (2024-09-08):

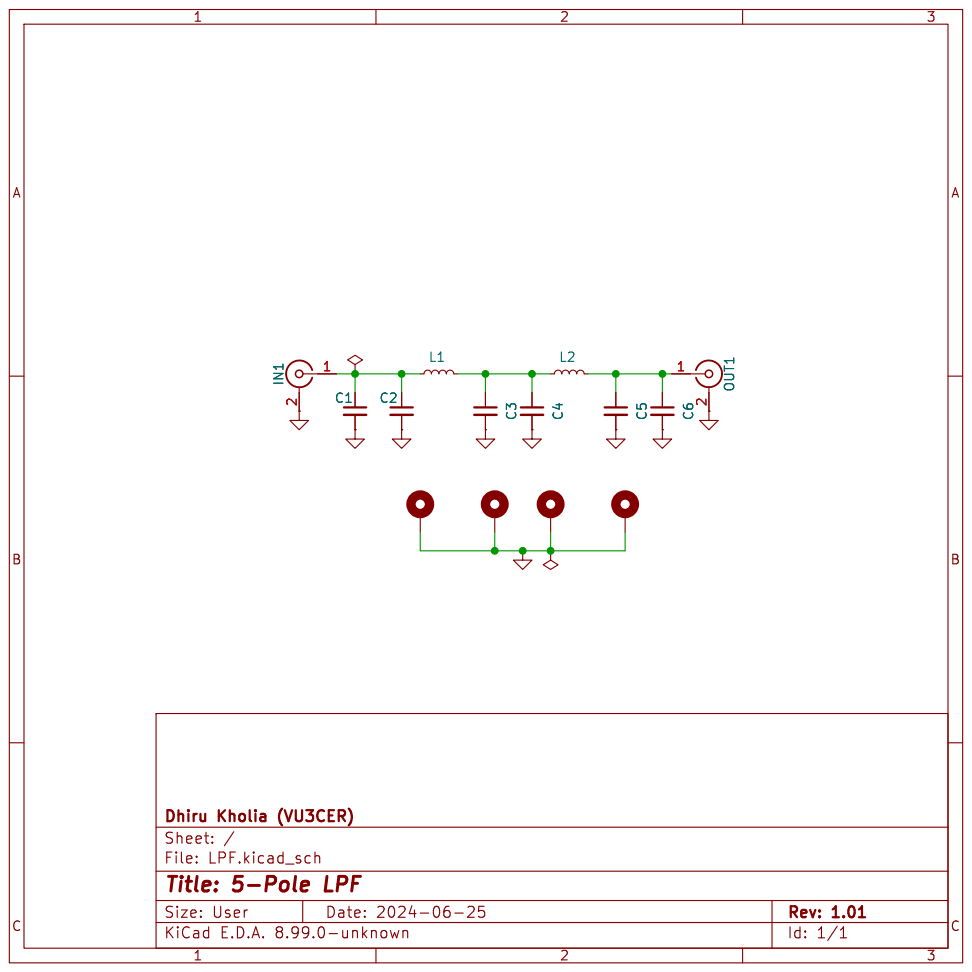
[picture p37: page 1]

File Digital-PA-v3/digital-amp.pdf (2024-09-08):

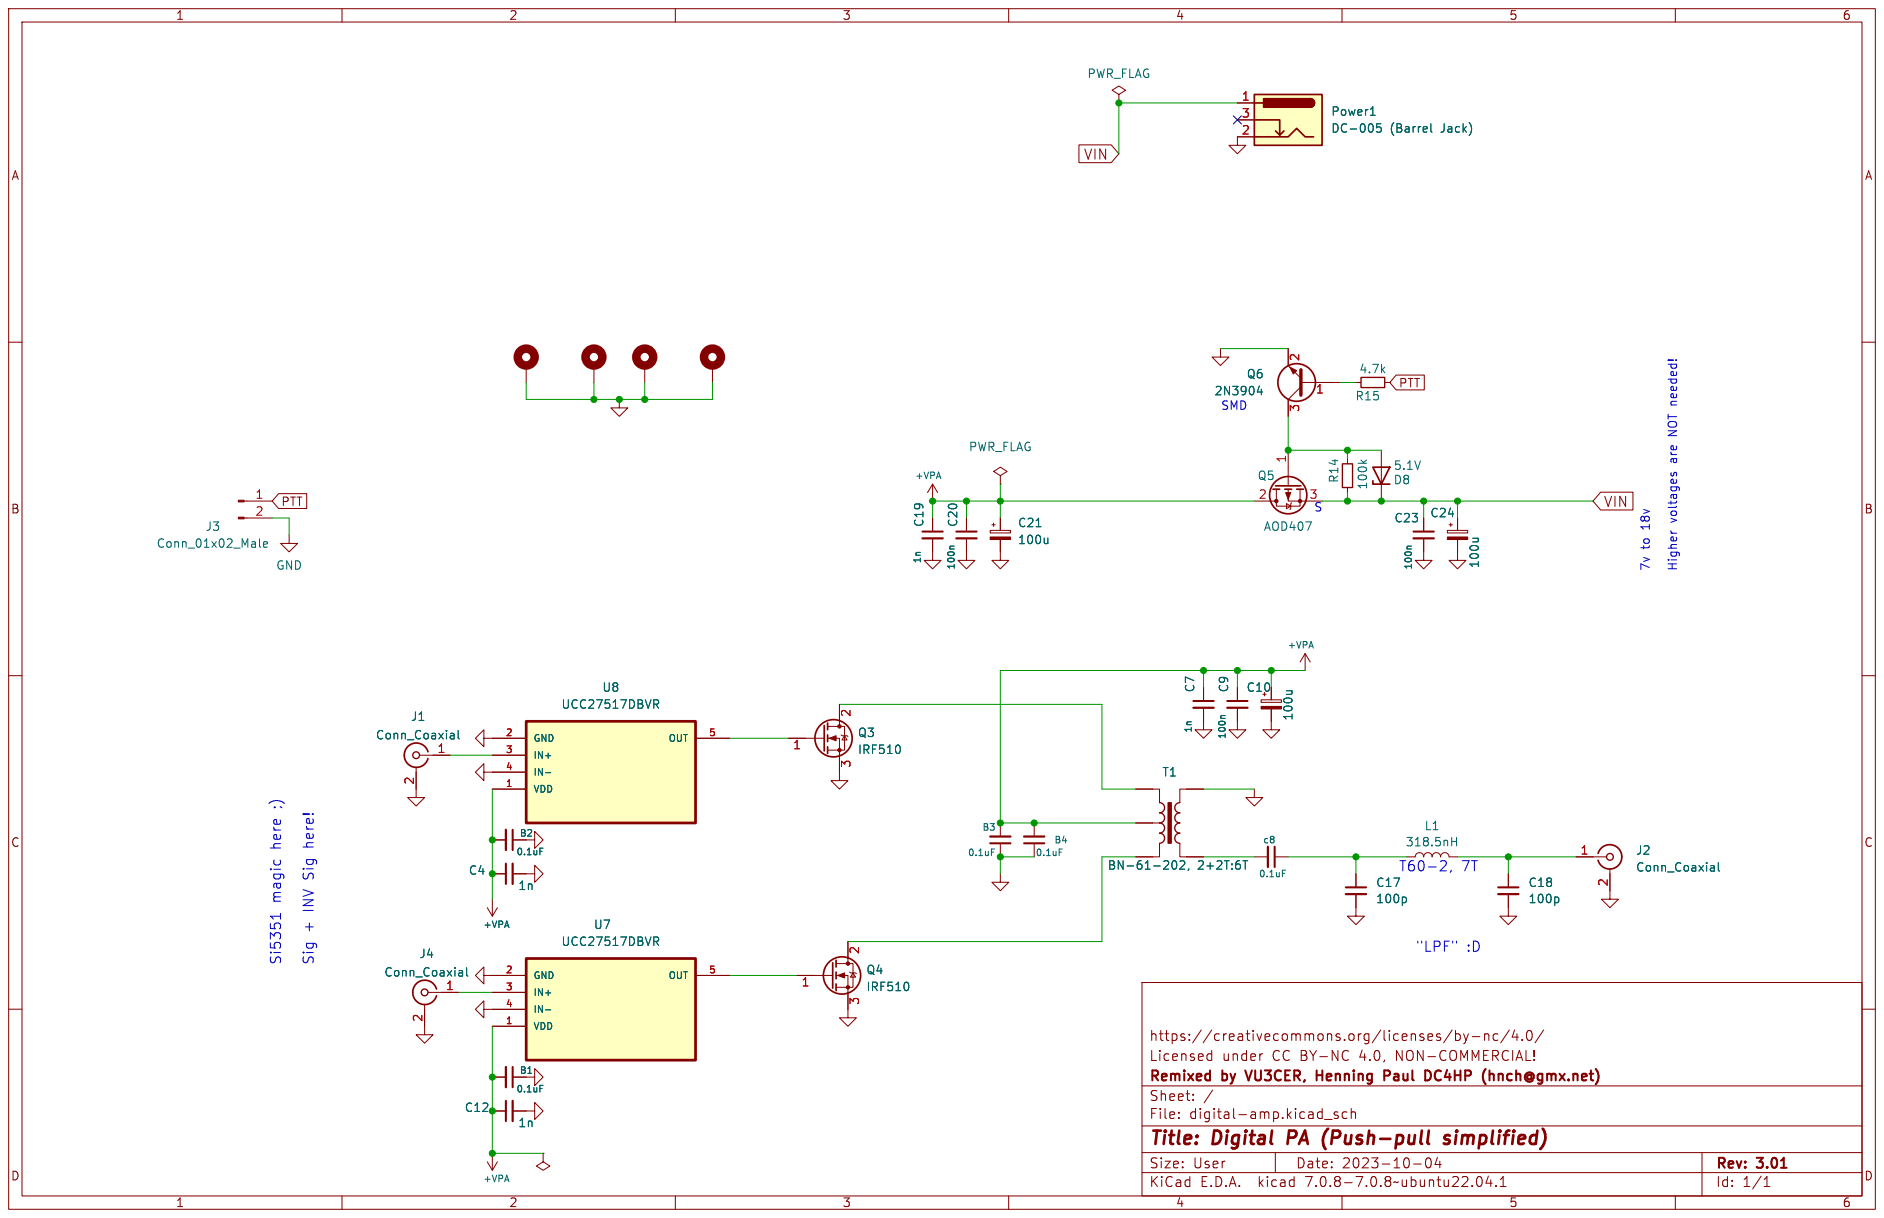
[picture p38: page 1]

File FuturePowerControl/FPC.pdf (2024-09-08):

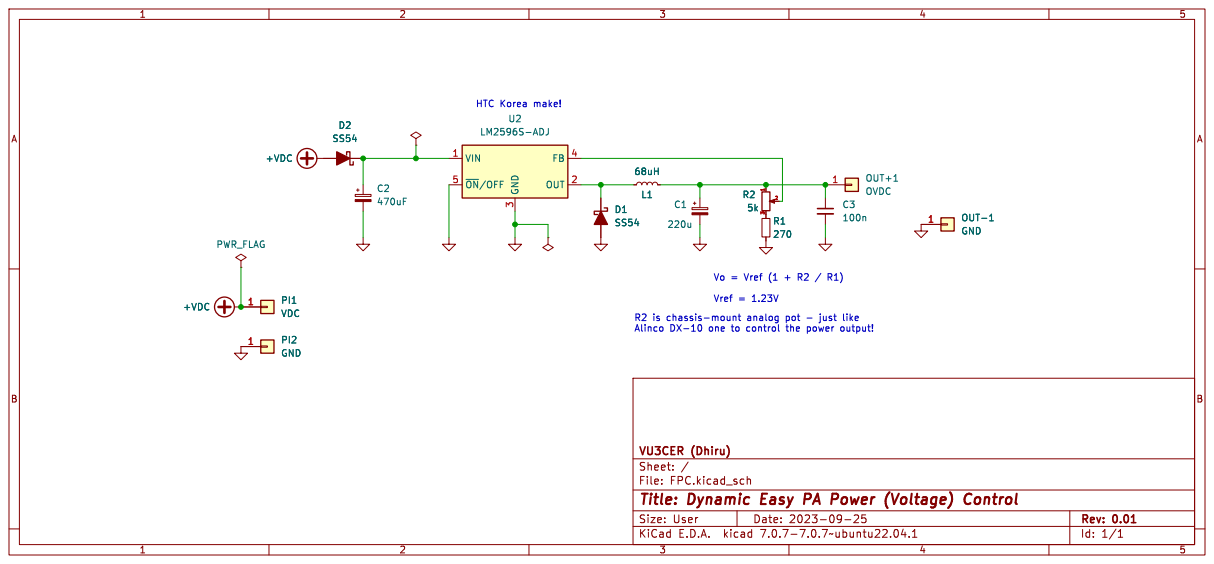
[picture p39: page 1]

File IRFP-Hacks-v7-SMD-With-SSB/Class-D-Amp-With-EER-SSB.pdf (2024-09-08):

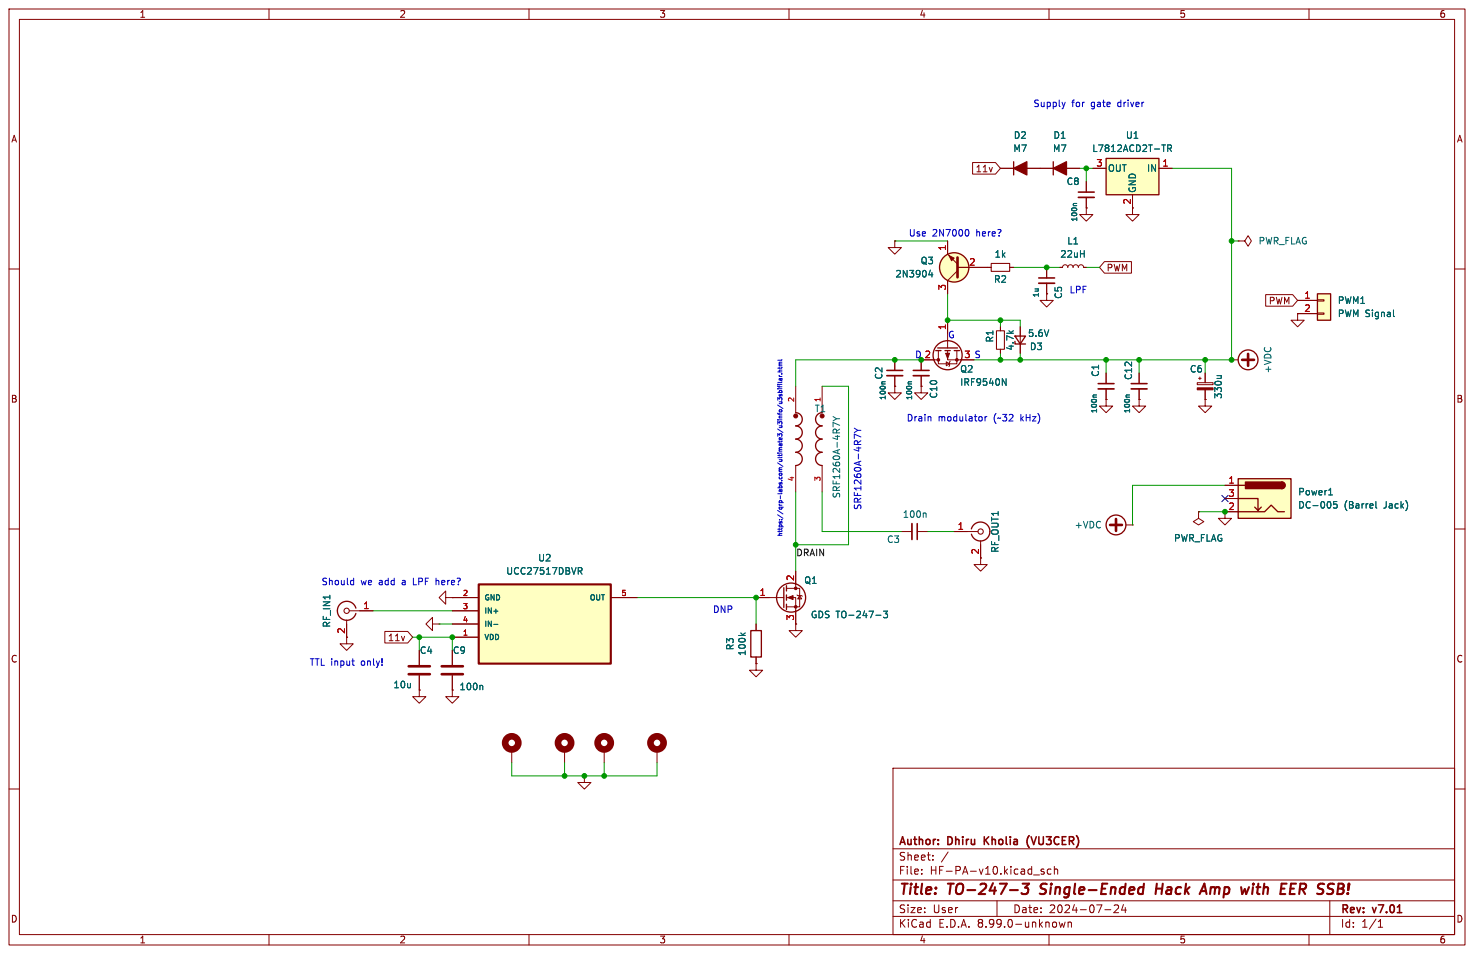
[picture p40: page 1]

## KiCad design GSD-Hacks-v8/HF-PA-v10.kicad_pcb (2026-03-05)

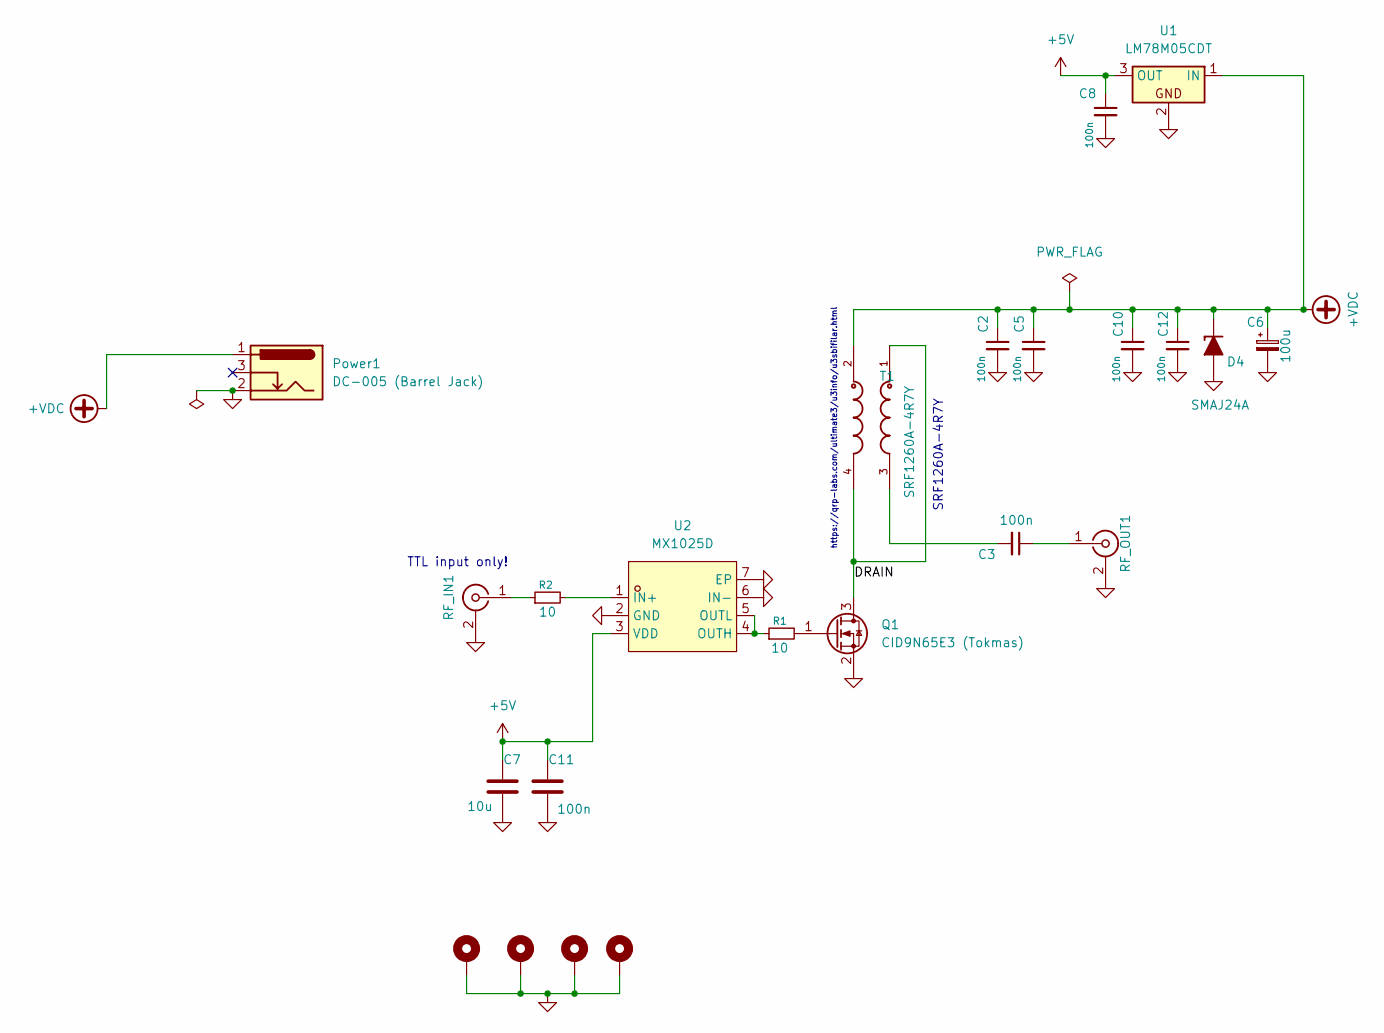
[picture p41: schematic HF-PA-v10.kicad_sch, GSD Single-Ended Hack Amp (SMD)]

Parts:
C2, C10: 100n; C_0805_2012Metric; LCSC Part C24783
C3, C8: 100n; C_0805_2012Metric; LCSC Part C110255
C5, C12: 100n; C_0805_2012Metric; LCSC Part C55077
C6: 100u; CP_Elec_8x10.5
C7: 10u; C_0805_2012Metric; LCSC Part C110255
C11: 100n; C_0805_2012Metric; LCSC Part C13585
D4: SMAJ24A; D_SMA
H1, H2, H3, H4: MountingHole_Pad; MountingHole_3.2mm_M3_Pad_Via
Power1: DC-005 (Barrel Jack); XKB_DC-005-5A-2.0_Modded
Q1: CID9N65E3 (Tokmas); TO-252-2_L6.6-W6.1-P4.57-LS9.9-BR-CW
R1, R2: 10; R_0603_1608Metric_Pad0.98x0.95mm_HandSolder
RF_IN1: SMA; SMA_Samtec_SMA-J-P-H-ST-EM1_EdgeMount
RF_OUT1: SMA; SMA_Samtec_SMA-J-P-H-ST-EM1_EdgeMount
T1: SRF1260A-4R7Y; IND_SRF1260A-4R7Y-Longer-Pads; LCSC Part C3273481
U1: LM78M05CDT; TO-252-2-Longer
U2: MX1025D; TDFN-6_L2.0-W2.0-P0.65-BL-EP; LCSC Part C5341121

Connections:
+5V: C7.1, C8.1, C11.1, U1.3 (OUT), U2.3 (VDD)
+VDC: C2.1, C5.1, C6.1, C10.1, C12.1, D4.1 (K), Power1.1, T1.2, U1.1 (IN)
/DRAIN: Q1.3 (D), T1.1, T1.4
GND: C2.2, C5.2, C6.2, C7.2, C8.2, C10.2, C11.2, C12.2, D4.2 (A), H1.1, H2.1, H3.1, H4.1, Power1.2, Q1.2 (S), RF_IN1.2 (Ext), RF_OUT1.2 (Ext), U1.2, U2.2 (GND), U2.6 (IN-), U2.7 (EP)
unnamed: C3.2, T1.3
unnamed: Q1.1 (G), R1.2
unnamed: R2.1, RF_IN1.1 (In)
unnamed: C3.1, RF_OUT1.1 (In)
unnamed: R2.2, U2.1 (IN+)
unnamed: R1.1, U2.4 (OUTH), U2.5 (OUTL)

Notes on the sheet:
https://qrp-labs.com/ultimate3/u3info/u3sbifilar.html
SRF1260A-4R7Y
TTL input only!

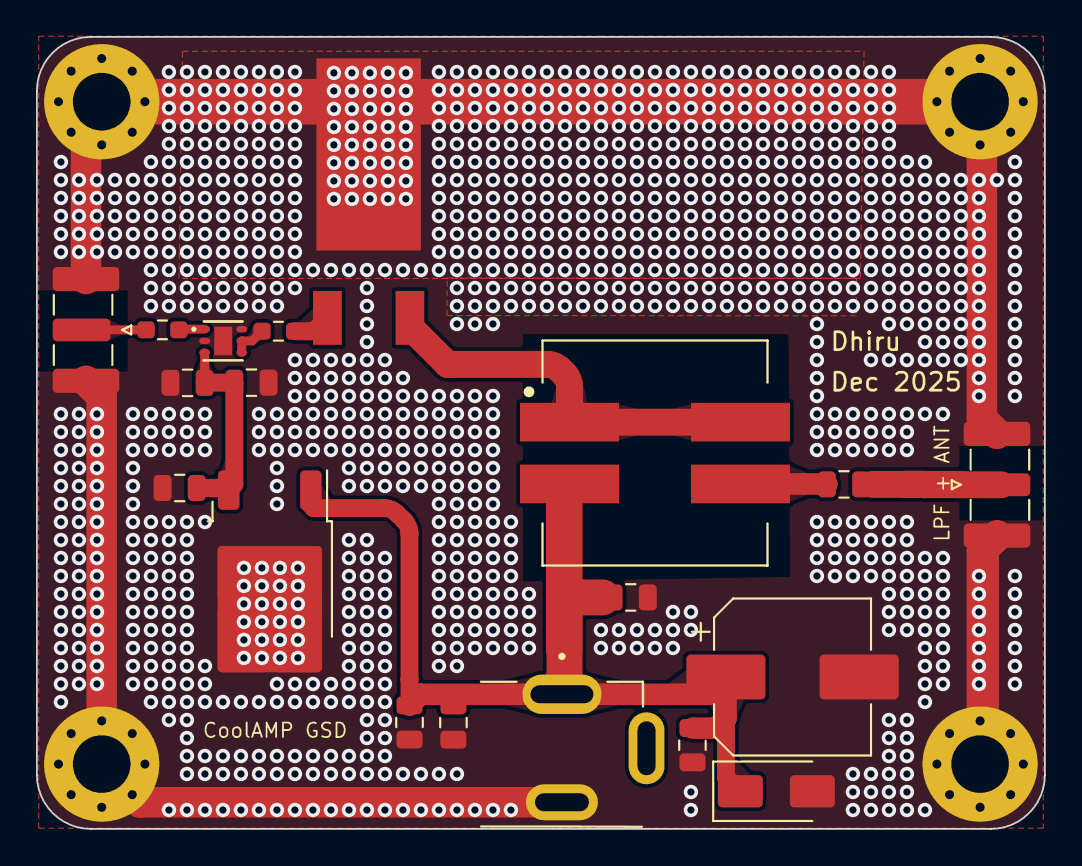
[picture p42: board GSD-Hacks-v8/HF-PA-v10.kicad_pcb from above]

Board: 2 copper layers, 56.0 x 44.0 mm, 23 parts (0 on the bottom side), 10 nets.

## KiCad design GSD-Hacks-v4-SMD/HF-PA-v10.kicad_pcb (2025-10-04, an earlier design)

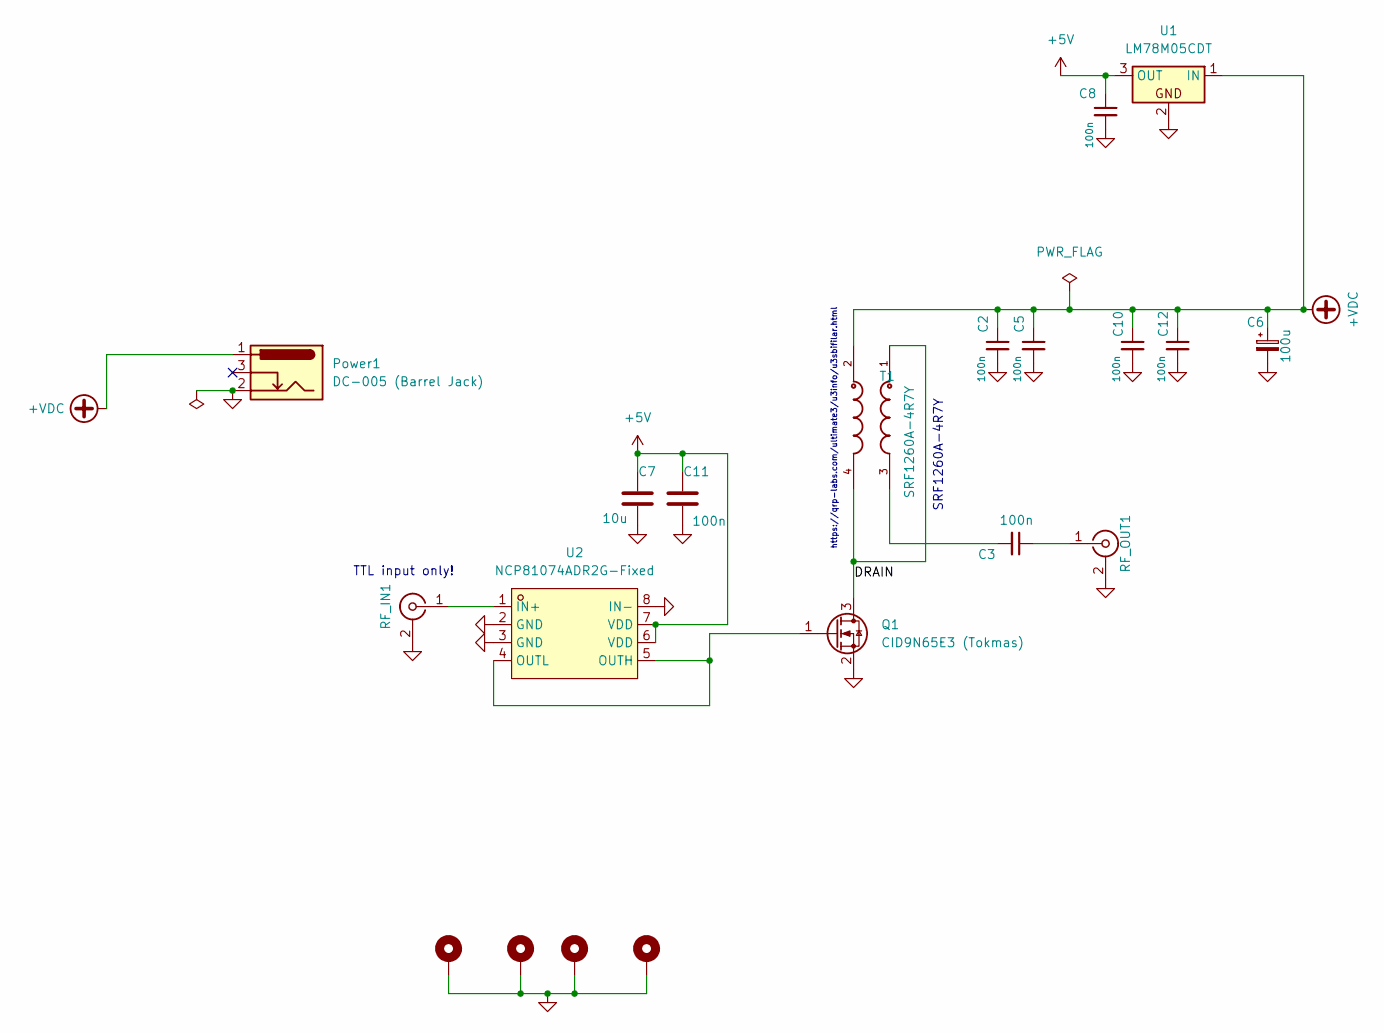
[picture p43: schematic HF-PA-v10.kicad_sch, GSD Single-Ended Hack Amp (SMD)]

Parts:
C2, C10: 100n; C_1206_3216Metric_Pad1.33x1.80mm_HandSolder; LCSC Part C24783
C3, C8: 100n; C_1206_3216Metric_Pad1.33x1.80mm_HandSolder; LCSC Part C110255
C5, C12: 100n; C_1206_3216Metric_Pad1.33x1.80mm_HandSolder; LCSC Part C55077
C6: 100u; CP_Radial_D8.0mm_P5.00mm
C7: 10u; C_1206_3216Metric_Pad1.33x1.80mm_HandSolder; LCSC Part C110255
C11: 100n; C_1206_3216Metric_Pad1.33x1.80mm_HandSolder; LCSC Part C13585
H1, H2, H3, H4: MountingHole_Pad; MountingHole_3.2mm_M3_Pad_Via
Power1: DC-005 (Barrel Jack); XKB_DC-005-5A-2.0_Modded
Q1: CID9N65E3 (Tokmas); TO-252-2_L6.6-W6.1-P4.57-LS9.9-BR-CW
RF_IN1: SMA; SMA_Samtec_SMA-J-P-H-ST-EM1_EdgeMount
RF_OUT1: SMA; SMA_Samtec_SMA-J-P-H-ST-EM1_EdgeMount
T1: SRF1260A-4R7Y; IND_SRF1260A-4R7Y-Longer-Pads; LCSC Part C3273481
U1: LM78M05CDT; TO-252-2
U2: NCP81074ADR2G-Fixed; SOIC-8_3.9x4.9mm_P1.27mm; LCSC Part C603800

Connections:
+5V: C7.1, C8.1, C11.1, U1.3 (OUT), U2.6 (VDD), U2.7 (VDD)
+VDC: C2.1, C5.1, C6.1, C10.1, C12.1, Power1.1, T1.2, U1.1 (IN)
/DRAIN: Q1.3 (D), T1.1, T1.4
GND: C2.2, C5.2, C6.2, C7.2, C8.2, C10.2, C11.2, C12.2, H1.1, H2.1, H3.1, H4.1, Power1.2, Q1.2 (S), RF_IN1.2 (Ext), RF_OUT1.2 (Ext), U1.2, U2.2 (GND), U2.3 (GND), U2.8 (IN-)
unnamed: C3.2, T1.3
unnamed: Q1.1 (G), U2.4 (OUTL), U2.5 (OUTH)
unnamed: RF_IN1.1 (In), U2.1 (IN+)
unnamed: C3.1, RF_OUT1.1 (In)

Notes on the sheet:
https://qrp-labs.com/ultimate3/u3info/u3sbifilar.html
SRF1260A-4R7Y
TTL input only!

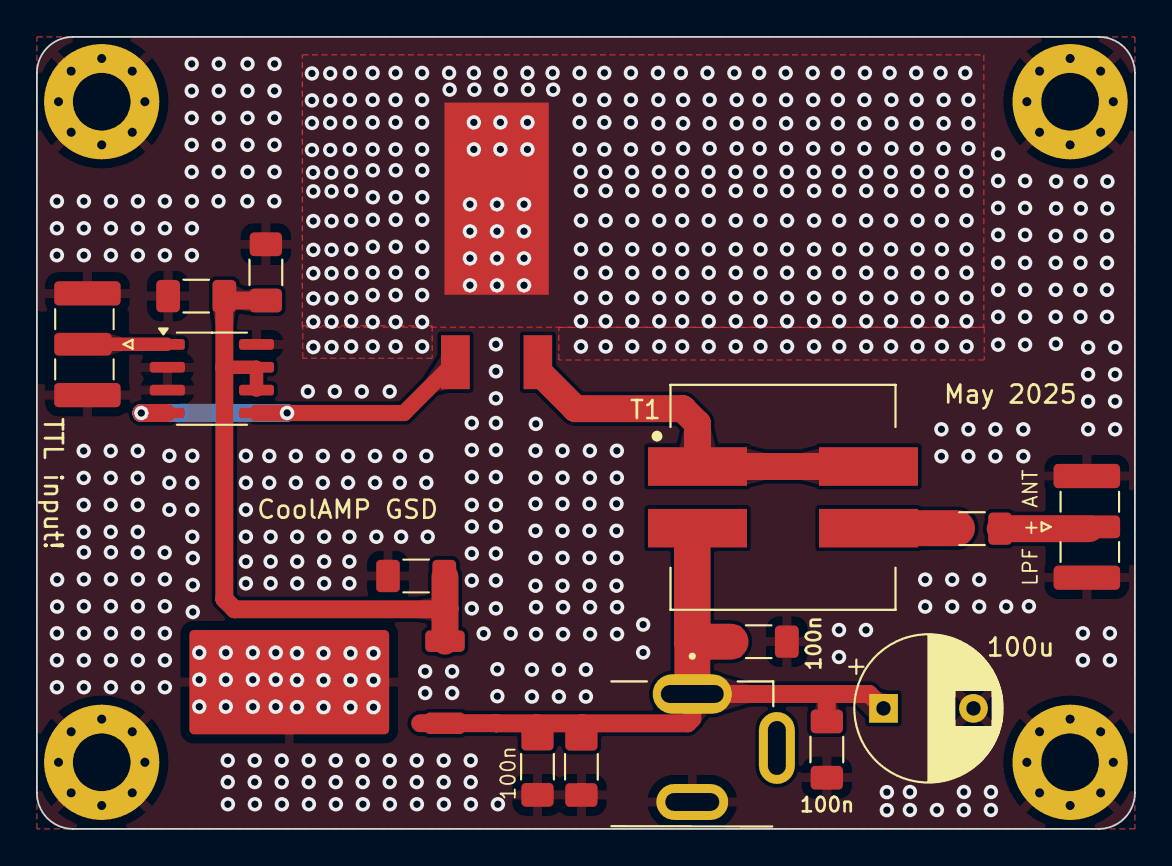
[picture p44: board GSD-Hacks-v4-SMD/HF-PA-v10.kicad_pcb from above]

Board: 2 copper layers, 61.0 x 44.0 mm, 20 parts (0 on the bottom side), 8 nets.

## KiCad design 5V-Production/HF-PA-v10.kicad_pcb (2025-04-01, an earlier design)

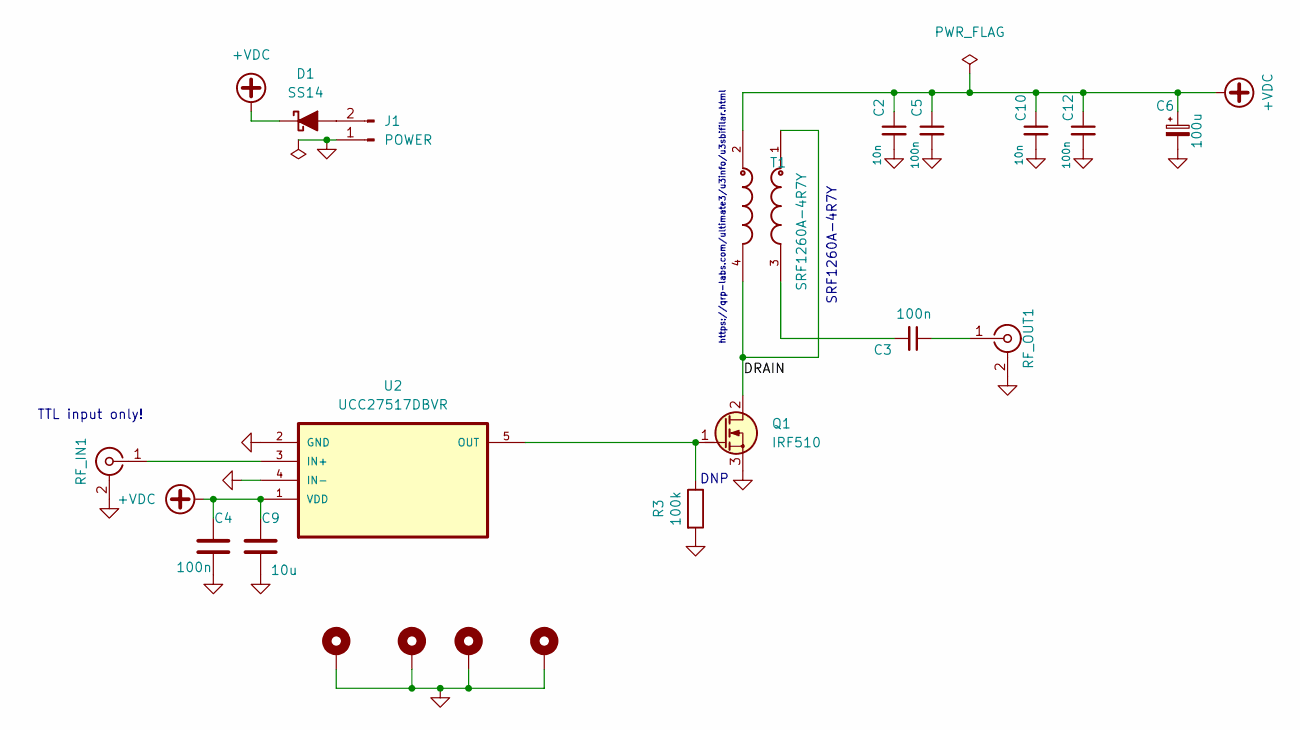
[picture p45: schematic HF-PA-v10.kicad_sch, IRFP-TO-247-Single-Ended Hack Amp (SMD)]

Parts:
C2, C10: 10n; C_1206_3216Metric_Pad1.33x1.80mm_HandSolder; LCSC Part C24783
C3, C4: 100n; C_1206_3216Metric_Pad1.33x1.80mm_HandSolder; LCSC Part C110255
C5, C12: 100n; C_1206_3216Metric_Pad1.33x1.80mm_HandSolder; LCSC Part C55077
C6: 100u; CP_Radial_D8.0mm_P3.50mm
C9: 10u; C_1206_3216Metric_Pad1.33x1.80mm_HandSolder; LCSC Part C13585
D1: SS14; D_SMA_Handsoldering
H1, H2, H3, H4: MountingHole_Pad; MountingHole_3.2mm_M3_Pad_Via
J1: POWER; JST_PH_B2B-PH-K_1x02_P2.00mm_Vertical
Q1: IRF510; TO-220-3_Horizontal_TabDown
R3: 100k; R_1206_3216Metric_Pad1.30x1.75mm_HandSolder; LCSC Part C17900
RF_IN1: SMA; SMA_Samtec_SMA-J-P-H-ST-EM1_EdgeMount
RF_OUT1: SMA; SMA_Samtec_SMA-J-P-H-ST-EM1_EdgeMount
T1: SRF1260A-4R7Y; IND_SRF1260A-4R7Y-Longer-Pads; LCSC Part C3273481
U2: UCC27517DBVR; TSOT-23-5_HandSoldering; LCSC Part C99395

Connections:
+VDC: C2.1, C4.1, C5.1, C6.1, C9.1, C10.1, C12.1, D1.1 (K), T1.2, U2.1 (VDD)
/DRAIN: Q1.2 (D), T1.1, T1.4
GND: C2.2, C4.2, C5.2, C6.2, C9.2, C10.2, C12.2, H1.1, H2.1, H3.1, H4.1, J1.1, Q1.3 (S), R3.2, RF_IN1.2 (Ext), RF_OUT1.2 (Ext), U2.2 (GND), U2.4 (IN-)
unnamed: C3.2, T1.3
unnamed: D1.2 (A), J1.2
unnamed: Q1.1 (G), R3.1, U2.5 (OUT)
unnamed: RF_IN1.1 (In), U2.3 (IN+)
unnamed: C3.1, RF_OUT1.1 (In)

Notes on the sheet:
DNP
https://qrp-labs.com/ultimate3/u3info/u3sbifilar.html
SRF1260A-4R7Y
TTL input only!

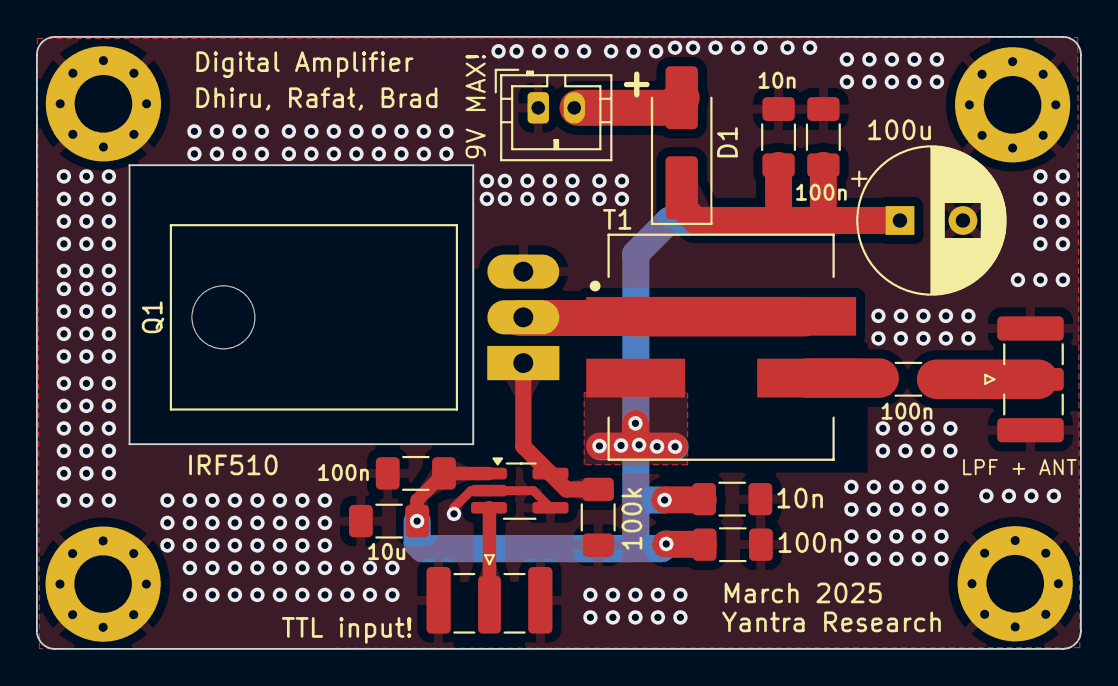
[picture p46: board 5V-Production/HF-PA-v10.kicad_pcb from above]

Board: 2 copper layers, 58.0 x 34.0 mm, 20 parts (0 on the bottom side), 8 nets.

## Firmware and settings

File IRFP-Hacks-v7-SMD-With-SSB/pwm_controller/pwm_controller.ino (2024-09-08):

// Drain modulator code

#include "RP2040_PWM.h"

//creates pwm instance
RP2040_PWM* PWM_Instance;

float frequency;
float dutyCycle;

#define pinToUse 16

#define AUDIO_INPUT_PIN A0    // Analog input pin for audio signal
// #define PWM_OUTPUT_PIN 9      // PWM output pin (must be PWM-capable)

const int SAMPLE_WINDOW = 50; // Sample window in ms (20 Hz)
const int PWM_FREQ = 31250;   // PWM frequency in Hz
const int PWM_RANGE = 255;    // PWM range (8-bit resolution)

// Raspberry Pi Pico
const int PWM_PIN = 16;
const int PWM_RESOLUTION = 8;  // PWM resolution in bits

unsigned long lastSample = 0;
int minAudioLevel = 1023;
int maxAudioLevel = 0;

void setup() {
  pinMode(AUDIO_INPUT_PIN, INPUT);
  // pinMode(PWM_OUTPUT_PIN, OUTPUT);

  // Initialize PWM
  // analogWriteFreq(PWM_FREQ);
  // analogWriteRange(1 << PWM_RESOLUTION);

  // Set up the PWM pin
  // pinMode(PWM_PIN, OUTPUT);

  // Start the PWM signal at 50% duty cycle
  // analogWrite(PWM_PIN, (1 << PWM_RESOLUTION) / 2);

  // Set PWM frequency (31250 Hz on pins 9 and 10)
  // TCCR1B = (TCCR1B & 0b11111000) | 0x01; // For Arduino Nano and similar

  PWM_Instance = new RP2040_PWM(pinToUse, PWM_FREQ, 50);
  frequency = PWM_FREQ;
  dutyCycle = 50;
  PWM_Instance->setPWM(pinToUse, frequency, dutyCycle);
  Serial.begin(115200);  // For debugging
}

void loop() {
  unsigned long currentMillis = millis();

  // Sample the audio input
  if (currentMillis - lastSample >= SAMPLE_WINDOW) {
    int pwmValue = sampleAudio();
    // analogWrite(PWM_PIN, pwmValue);

    // https://github.com/khoih-prog/RP2040_PWM/blob/main/examples/PWM_Basic/PWM_Basic.ino
    PWM_Instance->setPWM(pinToUse, frequency, pwmValue);

    // Print the PWM value for debugging
    // Serial.println(pwmValue);

    lastSample = currentMillis;
  }
}

int sampleAudio() {
  unsigned long startMillis = millis();
  int signalMax = 0;
  int signalMin = 1023;

  // Collect samples for SAMPLE_WINDOW milliseconds
  while (millis() - startMillis < SAMPLE_WINDOW) {
    int sample = analogRead(AUDIO_INPUT_PIN);
    if (sample > signalMax) {
      signalMax = sample;
    } else if (sample < signalMin) {
      signalMin = sample;
    }
  }

  int sample = analogRead(AUDIO_INPUT_PIN);
  Serial.println(sample);

  // Calculate peak-to-peak amplitude
  /* int peakToPeak = signalMax - signalMin;

    // Update global min/max levels (for automatic gain control)
    if (peakToPeak > maxAudioLevel) maxAudioLevel = peakToPeak;
    if (peakToPeak < minAudioLevel) minAudioLevel = peakToPeak; */

  // Map the amplitude to PWM range with some headroom
  // int pwmValue = map(peakToPeak, minAudioLevel, maxAudioLevel, 0, PWM_RANGE * 0.8);
  // pwmValue = constrain(pwmValue, 0, PWM_RANGE);

  int pwmValue = map(sample, 0, 1023, 0, PWM_RANGE * 0.8);
  pwmValue = constrain(pwmValue, 0, PWM_RANGE);

  // Invert PWM value for P-channel MOSFET
  // return PWM_RANGE - pwmValue;

  // We have a 2N3904 in front of P-channel MOSFET, so no PWM inversion is
  // needed!
  return pwmValue;
}

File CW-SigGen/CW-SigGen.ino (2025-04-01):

// https://github.com/ta2bgh/cw-beacon/blob/main/cw-beacon.ino

#include "si5351.h"

Si5351 si5351;

uint16_t duration = 85;  // Morse code typing speed in milliseconds - higher number means slower typing
uint64_t target_freq = 28023000ULL * 100ULL;
String cw_message = "VVV CQ CQ CQ DE VU3FOE";

void setup() {
  si5351.init(SI5351_CRYSTAL_LOAD_8PF, 0, 16999);
  si5351.output_enable(SI5351_CLK0, 0);
  pinMode(LED_BUILTIN, OUTPUT);
  digitalWrite(LED_BUILTIN, HIGH);

  delay(10000);
}

void loop() {
  digitalWrite(LED_BUILTIN, LOW);
  si5351.set_freq(target_freq, SI5351_CLK0);
  cw_string_proc(cw_message);
  cw(false);
  digitalWrite(LED_BUILTIN, HIGH);
  si5351.output_enable(SI5351_CLK0, 0);
  delay(5000);
}

void cw_string_proc(String str) {  // Processing string to characters
  for (uint8_t j = 0; j < str.length(); j++)
    cw_char_proc(str[j]);
}

void cw_char_proc(char m) {  // Processing characters to Morse symbols
  String s;

  if (m == ' ') {  // Pause between words
    word_space();
    return;
  }

  if (m > 96)  // ACSII, case change a-z to A-Z
    if (m < 123)
      m -= 32;

  switch (m) {  // Morse
    case 'A': s = ".-#"; break;
    case 'B': s = "-...#"; break;
    case 'C': s = "-.-.#"; break;
    case 'D': s = "-..#"; break;
    case 'E': s = ".#"; break;
    case 'F': s = "..-.#"; break;
    case 'G': s = "--.#"; break;
    case 'H': s = "....#"; break;
    case 'I': s = "..#"; break;
    case 'J': s = ".---#"; break;
    case 'K': s = "-.-#"; break;
    case 'L': s = ".-..#"; break;
    case 'M': s = "--#"; break;
    case 'N': s = "-.#"; break;
    case 'O': s = "---#"; break;
    case 'P': s = ".--.#"; break;
    case 'Q': s = "--.-#"; break;
    case 'R': s = ".-.#"; break;
    case 'S': s = "...#"; break;
    case 'T': s = "-#"; break;
    case 'U': s = "..-#"; break;
    case 'V': s = "...-#"; break;
    case 'W': s = ".--#"; break;
    case 'X': s = "-..-#"; break;
    case 'Y': s = "-.--#"; break;
    case 'Z': s = "--..#"; break;

    case '1': s = ".----#"; break;
    case '2': s = "..---#"; break;
    case '3': s = "...--#"; break;
    case '4': s = "....-#"; break;
    case '5': s = ".....#"; break;
    case '6': s = "-....#"; break;
    case '7': s = "--...#"; break;
    case '8': s = "---..#"; break;
    case '9': s = "----.#"; break;
    case '0': s = "-----#"; break;

    case '?': s = "..--..#"; break;
    case '=': s = "-...-#"; break;
    case ',': s = "--..--#"; break;
    case '/': s = "-..-.#"; break;
  }

  for (uint8_t i = 0; i < 7; i++) {
    switch (s[i]) {
      case '.': di(); break;           // di
      case '-': dah(); break;          // dah
      case '#': char_space(); return;  // end of morse symbol
    }
  }
}

void di() {
  cw(true);  // TX di
  delay(duration);

  cw(false);  // stop TX di
  delay(duration);
}

void dah() {
  cw(true);  // TX dah
  delay(3 * duration);

  cw(false);  // stop TX dah
  delay(duration);
}

void char_space() {     // 3x, pause between letters
  delay(2 * duration);  // 1x from end of character + 2x from the beginning of new character
}

void word_space() {     // 7x, pause between words
  delay(6 * duration);  // 1x from end of the word + 6x from the beginning of new word
}

void cw(bool state) {  // TX-CW, TX-LED, 750 Hz sound
  if (state) {
    si5351.set_freq(target_freq, SI5351_CLK0);
    si5351.output_enable(SI5351_CLK0, 1);
  } else {
    si5351.set_freq(target_freq, SI5351_CLK0);
    si5351.output_enable(SI5351_CLK0, 0);
  }
}

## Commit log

2024-09-08 Initial version
    [144743.stp, CON-SMA-EDGE-S--3DModel-STEP-56544.STEP, DC-005-5A-2.0.step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]
2025-04-01 SiC QRO Amplifier
    [744851330.stp, CON-SMA-EDGE-S--3DModel-STEP-56544.STEP, DC-005-5A-2.0.step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]
2025-10-04 GSD-Hacks-v4-SMD and v5
    [CON-SMA-EDGE-S--3DModel-STEP-56544.STEP, DC-005-5A-2.0.step, FK_244_13_D_PAK_TR.stp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]
2026-03-05 Add GSD-Hacks-v8
    [CON-SMA-EDGE-S--3DModel-STEP-56544.STEP, DC-005-5A-2.0.step, FK_244_13_D_PAK_TR.stp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]

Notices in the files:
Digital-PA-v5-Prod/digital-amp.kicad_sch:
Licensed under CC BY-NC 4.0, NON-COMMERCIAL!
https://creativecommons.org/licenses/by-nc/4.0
